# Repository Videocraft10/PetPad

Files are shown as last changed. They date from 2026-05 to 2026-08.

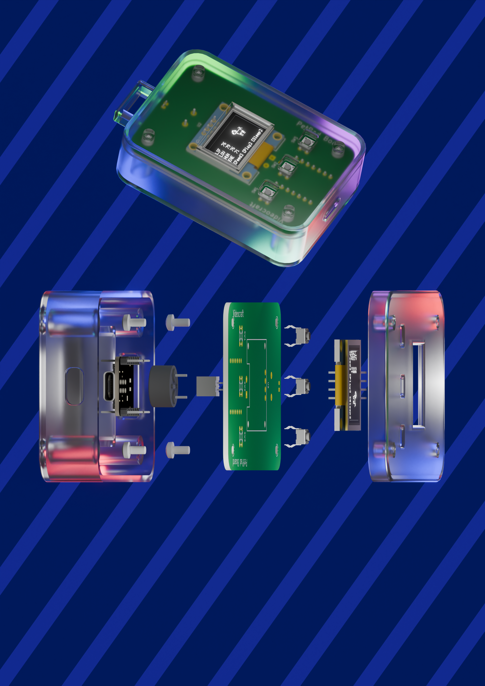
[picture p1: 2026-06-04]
Promo Files/Exports/Zine/Videocraft PetPad Zine Full.png

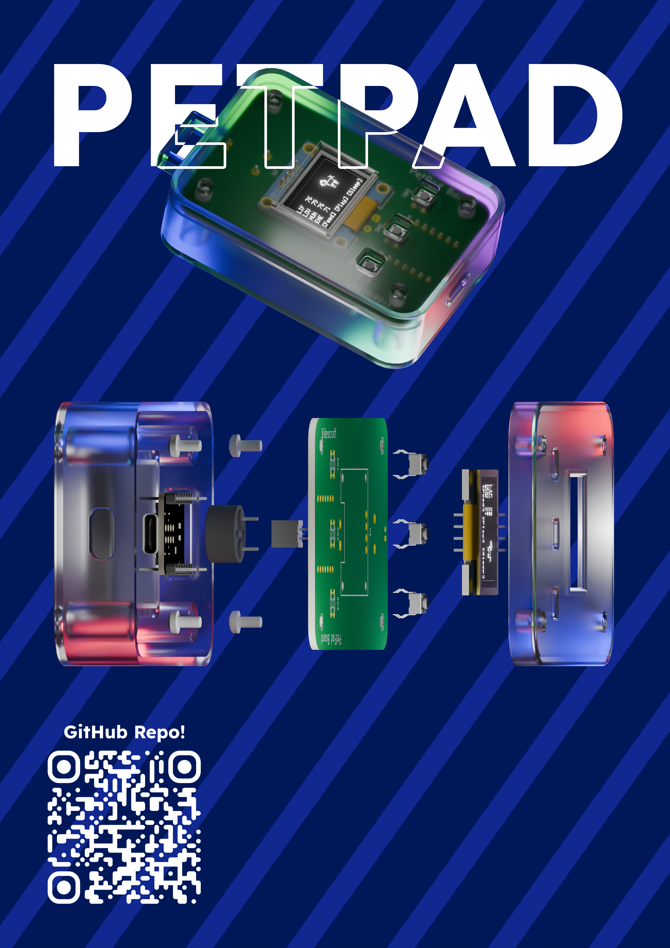
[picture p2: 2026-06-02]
Promo Files/Exports/Zine/Videocraft PetPad Zine 6-2-26.png

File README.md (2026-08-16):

# PetPad [WIP]
PetPad Main

Custom-Made Tamagotchi-Like Device

## Features
Videocraft PetPad Zine v1 BUILD

### Physical
1. USB - C rechargeable 500 mAh battery
2. 3 Tactile buttons for control
3. Buzzer for sound feedback
4. 128x64 OLED Screen

### Digital
1. [WIP] Multiple Pets to obtain
2. Take care (or don't) of your pets to see the visuals change
3. [WIP] Use items obtained randomly on your pets for effects

## Why?
I wanted to create this for a couple of reasons:
1. I wanted a more complex project to work on
2. Tamagotchis are fun and allow me to practice some pixel art skills too
3. And finally, because there was a great guide on the Fallout docs :)

## The PCB
The PCB was made in KiCAD due to the extensive tools and ability to import own footprints that might not be on EasyEDA

### The Schematic


### The Circuit Board
**Front**



**Back**



## The Case

**Overview**



**Top**



**Inside cut**



**Bottom**



## The Firmware
Firmware Video

Visible stats that change over time with visual feedback on overall pets health

## BOM
*Amount used is to make ****ONE**** PetPad*

| Item | LCSC # / Item Links | Single Cost | Amount Used | Fees/Notes | Total Price |
| --- | --- | --- | --- | --- | --- |
| **PCB:** | ---------- | $2 | 1 | $3.12 for shipping | $5.12 |
| ---------- | ---------- | ---------- | ---------- | ---------- | ---------- |
| **Components:** | ---------- | ---------- | ---------- | ---------- | ---------- |
| OLED Screen | [C5248080](https://www.lcsc.com/product-detail/C5248080.html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) | $2.32 | 1 | ---------- | $2.32 |
| Buzzer | [C49246964](https://www.lcsc.com/product-detail/C49246964.html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) | $0.0569 | 1 | Forced to buy 10 | $0.57 |
| Buttons | [C2888493](https://www.lcsc.com/product-detail/C2888493.html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) | $0.0107 | 3 | Forced to buy 50 | $0.54 |
| JST Battery Connector | [C131337](https://www.lcsc.com/product-detail/C131337.html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) | $0.0336 | 1 | Forced to buy 20 | $0.67 |
| 7 Pin Header | [C5360900](https://www.lcsc.com/product-detail/C5360900.html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) | $0.0391 | 2 | Forced to buy 10 | $0.39 |
| 4 Pin Header | [C42431787](https://www.lcsc.com/product-detail/C42431787.html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) | $0.0207 | 1 | Forced to buy 20 | $0.41 |
| Seeed Studio XIAO C6 DIP | [Amazon](https://www.amazon.com/ESP32C6-Supports-Bluetooth-802-15-4-Microsoft/dp/B0D2NKV334?th=1) | $11.99 | 1 | $0.79 tax | $12.78 |
| Battery (140mAh) | [AliExpress](https://www.aliexpress.us/item/3256808031709894.html?channel=twinner) | $1.06 | 1 | NOTE: INSANE SUMMER DEAL USED, NORMAL PRICE $14.23 | $1.06 |
| Screws (M2.5 x 5mm) | [Homedepot](https://www.homedepot.com/p/Prime-Line-M2-5-0-45-x-5-mm-Grade-A2-70-Stainless-Steel-Phillips-Drive-Pan-Head-Metric-Machine-Screws-10-Pack-9130825/311229791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) | $0.433 | 4* | 10 pack | $4.33 |
| Wires | [Amazon]([https://www.adafruit.com/product/3169](https://www.amazon.com/Fielect-Enamelled-Winding-Polyurethane-QA-1-155/dp/B082SGDHTT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)) | $7.48 | less than a foot most likely (WILL HAVE A TON LEFT OVER SO IF YOU HAVE SOMTHING SIMILAR DO NOT BUY) | 30 AWG Magnet Wire Enameled Copper Wire | $7.45 |
| ---------- | ---------- | ---------- | ---------- | ---------- | ---------- |
| *Total:* | ---------- | ---------- | ---------- | ---------- | $37.98 |
| **Fees:** | LCSC Tax $1.25 | ---------- | ---------- | ---------- | [wip] |
| Shipping | LCSC Shipping cost: $10.92 | ---------- | ---------- | ---------- | [wip]|
| Handling | LCSC Handling $3 | ---------- | ---------- | ---------- | $3 |
| ---------- | ---------- | ---------- | ---------- | ---------- | ---------- |
| ***TOTAL*** | ---------- | ---------- | ---------- | ---------- | $50.30 (fee prices not locked in yet) |

## Build BOM
| Item | Discripton | Notes | Fees | -------- | Total |
| --- | --- | --- | --- | --- | --- |
| 3D Printer PLA | Generic 3D printer PLA. Requires a 3D printer to use | Paid $8.34 for 1 kg | ---------- | ---------- | 46g used - $0.38 |
| Sodering Iron | ---------- | Required to soder on components | ---------- | ---------- | $10.55 [here](https://www.amazon.com/Soldering-Digital-Welding-Portable-Electric/dp/B08R3515SF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) |
| ---------- | ---------- | ---------- | ---------- | ---------- | ---------- |
| ***TOTAL*** | ---------- | ---------- | ---------- | ---------- | $10.93 |

***GRAND TOTAL*** = $60.68

## How to Build
> [!NOTE]
> It is recommended to have prior knowledge in electronics and soldering if you want to create one for yourself!

First download the PCB Gerber file from [here](https://github.com/Videocraft10/PetPad/tree/main/PCB%20Files) then send it to your preferred manufacturer! Next buy all of the components from the BOM. For screws and similar items, it is recommended to find the cheapest in your location. Next 3D print the case from here [here](https://github.com/Videocraft10/PetPad/tree/main/Case%20Files) and ensure the PCB fits once it arrives. Next solder on all of the components and screw the PCB into the case! Finally flash the firmware onto it from [here](https://github.com/Videocraft10/PetPad/tree/main/Firmware%20Files/PetPad_Firm) (you might have to build the file on you own computer)

Tada! You now have a PetPad!

(instructions on how to build will improves once I actually physically build one myself :D)

## Software Used
1. KiCAD
2. Autodesk Fusion
3. Blender
4. Visual Studio Code (Arduino Maker Workshop & Wokwi extentsihons)
5. Arduino IDE
6. Adobe Photoshop
7. Adobe Preimimre Pro
8. Visual Studio Code

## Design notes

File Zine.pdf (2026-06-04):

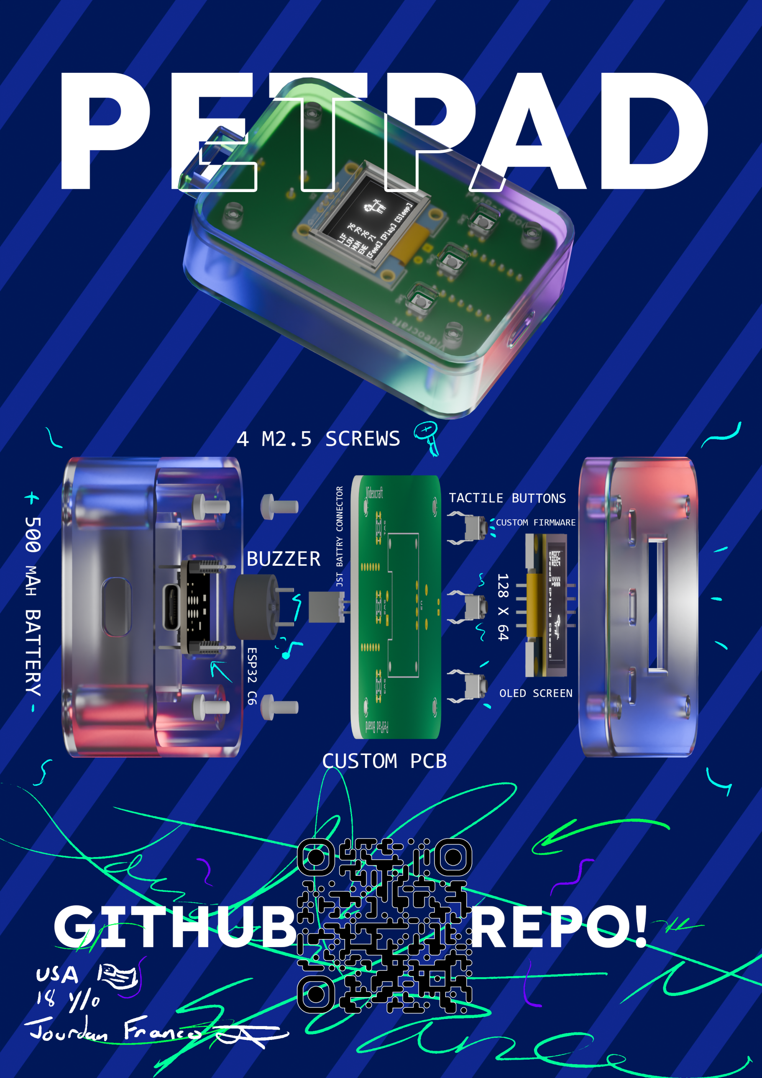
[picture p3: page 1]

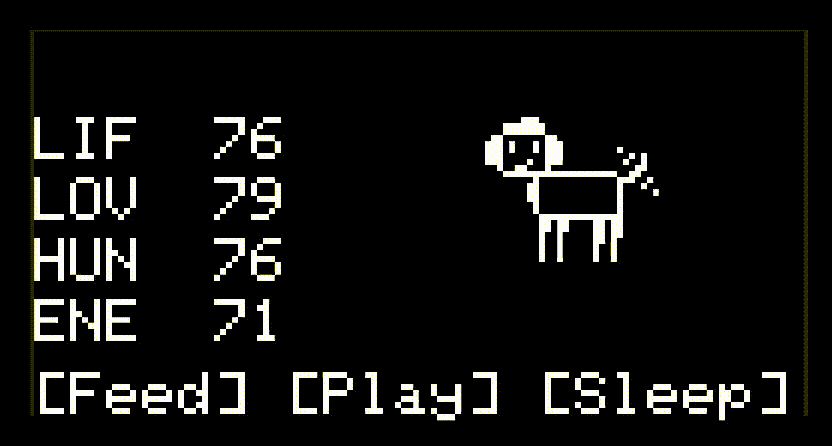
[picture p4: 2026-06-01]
Promo Files/Exports/Firmware Video.gif

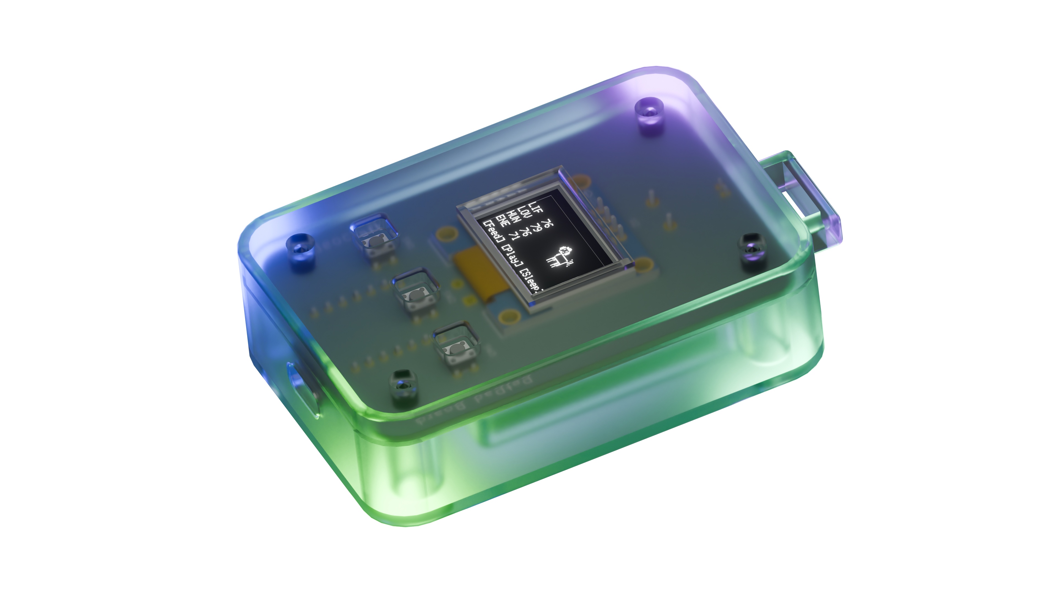
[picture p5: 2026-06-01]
Promo Files/Exports/PetPad Repo Color Cover v0.png

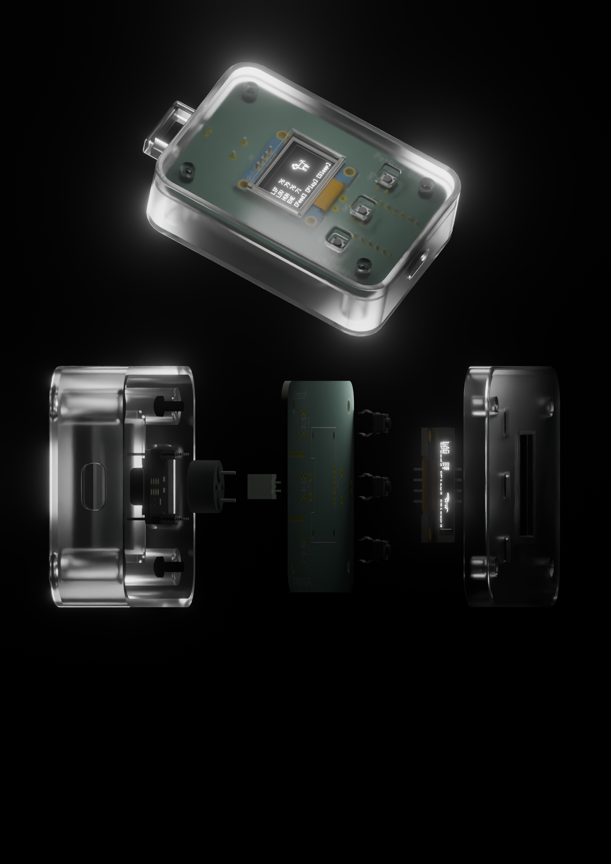
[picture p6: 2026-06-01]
Promo Files/Exports/Zine/Videocraft PetPad Zine 6-1-26.png

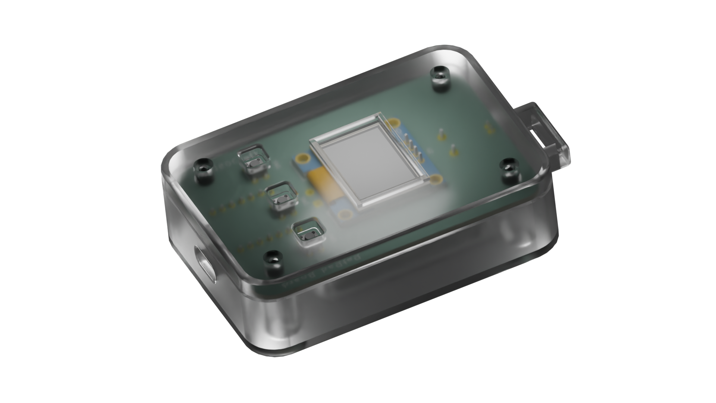
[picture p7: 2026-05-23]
Promo Files/Exports/PetPad Repo Cover v0.png

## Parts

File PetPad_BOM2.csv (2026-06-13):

Item | Link/Description | Single Cost | Amount Used | Notes | Total Price
PCB | - | $2.00 | 1 | $3.12 for shipping | $5.12
OLED Screen | https://www.lcsc.com/product-detail/C5248080.html | $2.32 | 1 | - | $2.32
Buzzer | https://www.lcsc.com/product-detail/C49246964.html | $0.0569 | 1 | Forced to buy 10 | $0.57
Buttons | https://www.lcsc.com/product-detail/C2888493.html | $0.0107 | 3 | Forced to buy 50 | $0.54
JST Battery Connector | https://www.lcsc.com/product-detail/C131337.html | $0.0336 | 1 | Forced to buy 20 | $0.67
7 Pin Header | https://www.lcsc.com/product-detail/C5360900.html | $0.0391 | 2 | Forced to buy 10 | $0.39
4 Pin Header | https://www.lcsc.com/product-detail/C42431787.html | $0.0207 | 1 | Forced to buy 20 | $0.41
Seeed Studio XIAO C6 DIP | https://www.amazon.com/ESP32C6-Supports-Bluetooth-802-15-4-Microsoft/dp/B0D2NKV334 | $11.99 | 1 | $0.79 tax | $12.78
Battery (500mAh) | https://www.aliexpress.us/item/3256808031709894.html | $1.06 | 1 | NOTE: INSANE SUMMER DEAL USED, NORMAL PRICE $14.23 | $1.06
Screws (M2 x 5mm) | https://www.homedepot.com/p/Prime-Line-M2-5-0-45-x-5-mm-Grade-A2-70-Stainless-Steel-Phillips-Drive-Pan-Head-Metric-Machine-Screws-10-Pack-9130825/311229791 | $0.433 | 4 | 10 pack | $4.33
Wires | https://www.amazon.com/Fielect-Enamelled-Winding-Polyurethane-QA-1-155/dp/B082SGDHTT | $7.48 | less than a foot | 30 AWG Magnet Wire. WILL HAVE A TON LEFT OVER SO IF YOU HAVE SOMTHING SIMILAR DO NOT BUY | $7.45
Subtotal | - | - | - | - | $37.98
LCSC Tax | - | - | - | - | $1.25
LCSC Shipping | - | - | - | - | $10.92
LCSC Handling | - | - | - | - | $3.00
TOTAL (PetPad Estimated) | - | - | - | fee prices not locked in yet | $50.30
3D Printer PLA | Generic 3D printer PLA. Requires a 3D printer to use. | $8.34 for 1 kg | 46g used | - | $0.38
Soldering Iron | https://www.amazon.com/Soldering-Digital-Welding-Portable-Electric/dp/B08R3515SF | $10.55 | 1 | Required to solder on components | $10.55
TOTAL (Build Tools) | - | - | - | - | $10.93

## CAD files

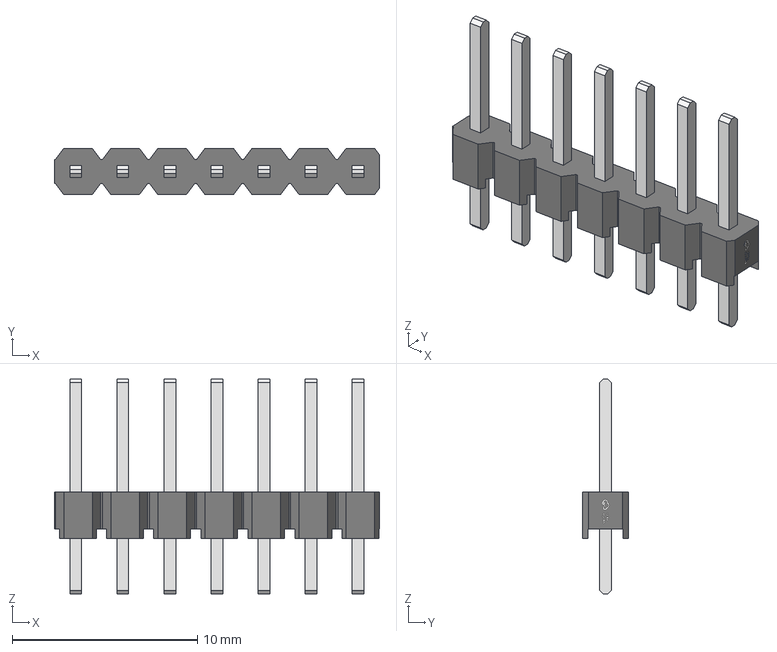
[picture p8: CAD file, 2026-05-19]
CAD Files/Componet STEP Files/7 Pin header.step
17.5 x 2.50 x 11.6 mm

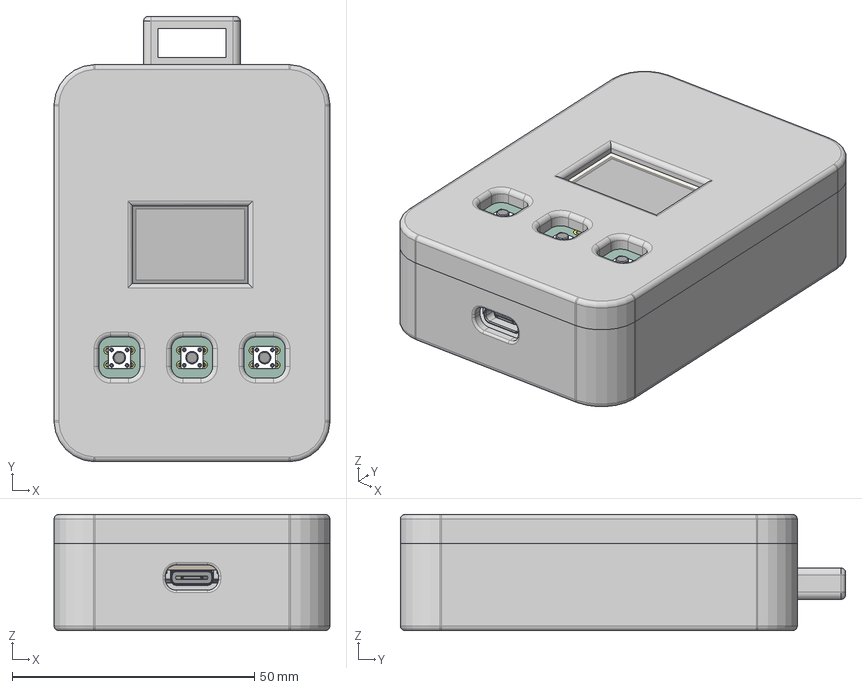
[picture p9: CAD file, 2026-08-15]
CAD Files/Videocraft PetPad.step
57.0 x 92.0 x 24.0 mm
DIN 7985 - M2.5x5-H H Steel 4.6 Zinc x 4

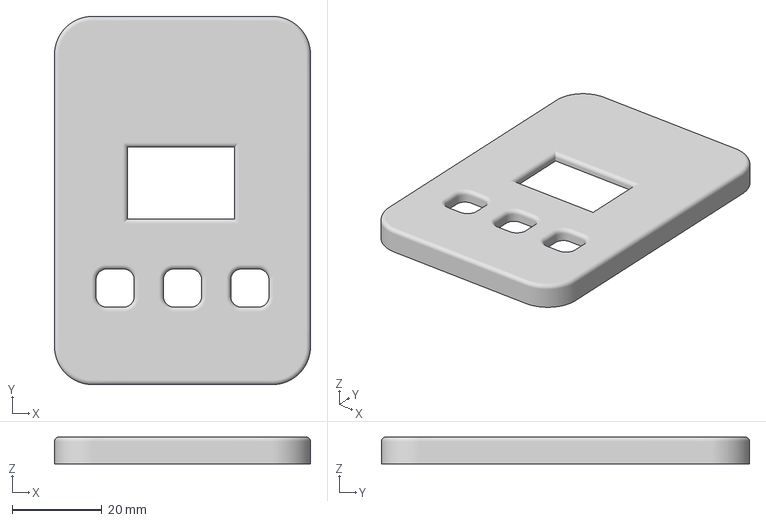
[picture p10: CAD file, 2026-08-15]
Case Files/PetPad Case Top.3mf
57.0 x 82.0 x 6.00 mm

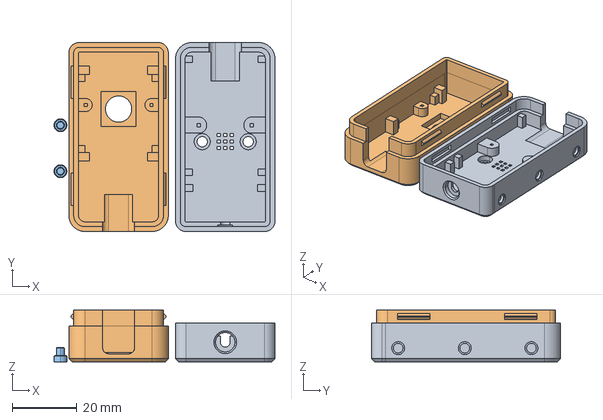
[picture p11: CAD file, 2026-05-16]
KiCad Files/OPL_Kicad_Library-master/Grove Vision AI V2 Library/himax.stp
68.4 x 58.5 x 16.1 mm

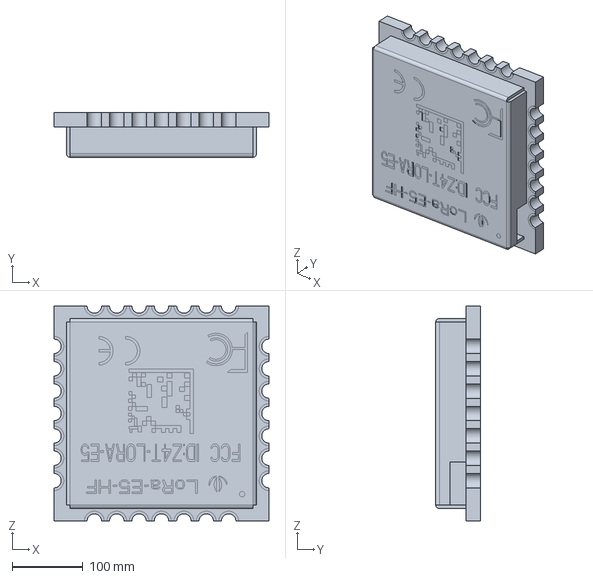
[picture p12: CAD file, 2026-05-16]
KiCad Files/OPL_Kicad_Library-master/Seeed Studio Wio Series/Wio-E5-LE/LoRa-E5-LE-HF_3D_File.stp
304.8 x 63.8 x 304.8 mm

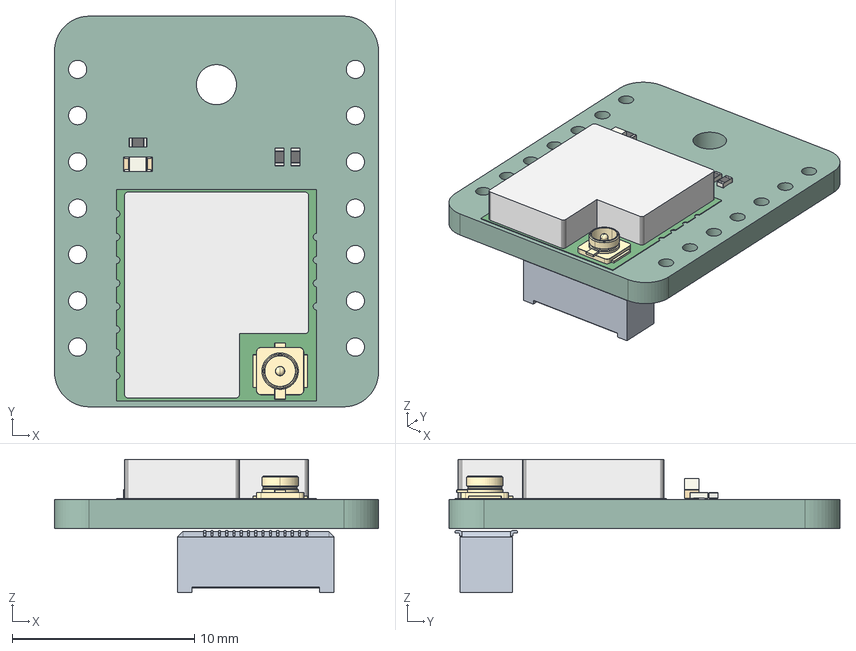
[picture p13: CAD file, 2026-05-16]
KiCad Files/OPL_Kicad_Library-master/Seeed Studio Wio Series/Wio-SX1262/Wio-SX1262_for_XIAO_3D_file.step
17.8 x 21.4 x 7.30 mm
R_0402_1005Metric x 3
LED_0603_1608Metric
PCB
BF04-30pin-35H
Wio-SX1262 for XIAO V1.0_PCB

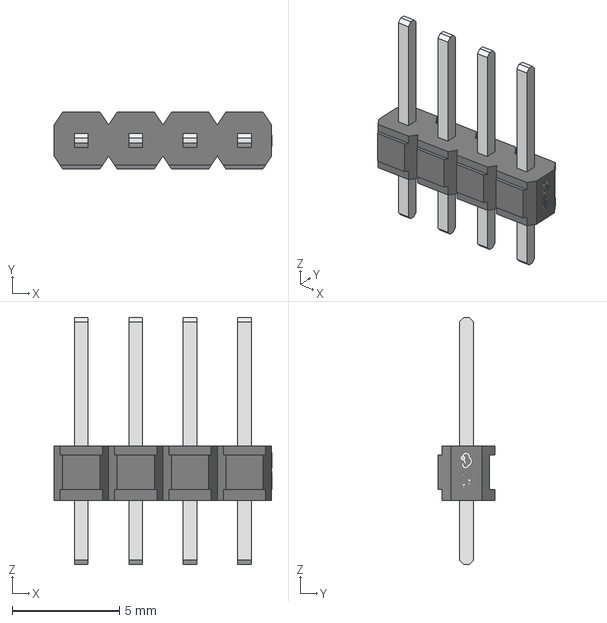
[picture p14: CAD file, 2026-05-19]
CAD Files/Componet STEP Files/4 Pin Header.step
10.2 x 2.66 x 11.5 mm

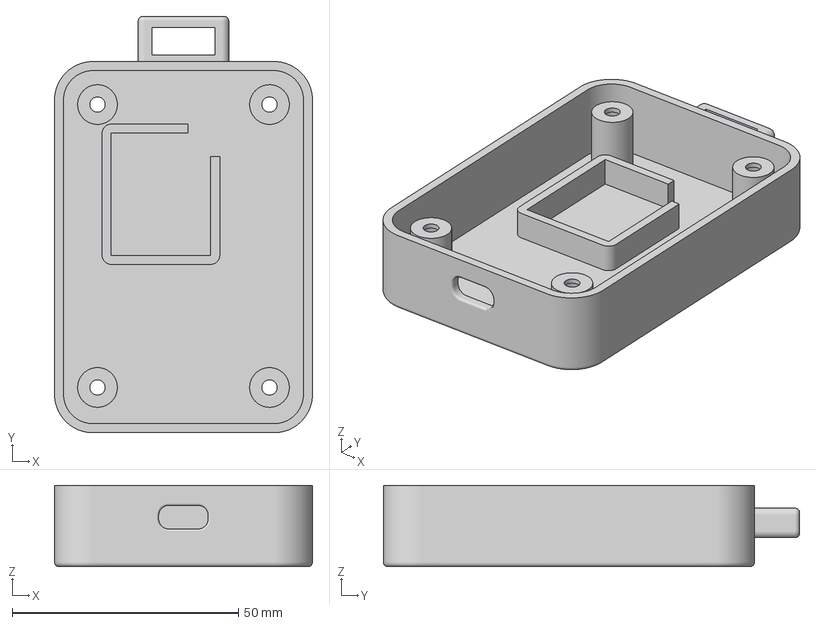
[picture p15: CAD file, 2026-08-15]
Case Files/PetPad Case Bottom.3mf
57.0 x 92.0 x 18.0 mm

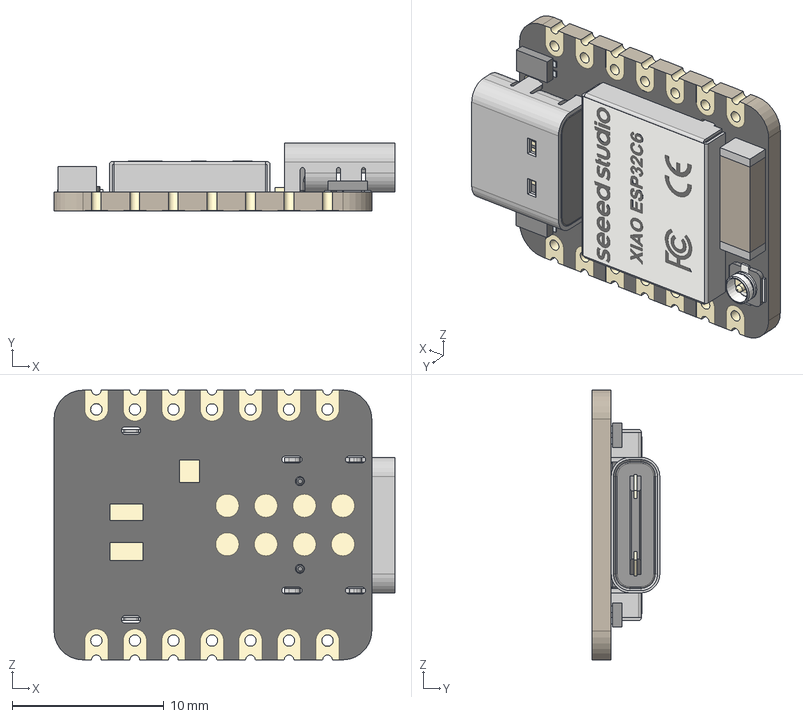
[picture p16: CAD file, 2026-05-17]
CAD Files/Componet STEP Files/seeed-studio-xiao-esp32c6-v2.step
22.5 x 4.46 x 17.8 mm
BOSS-EXTRUDE14_8_
BOSS-EXTRUDE7_4_
BOSS-EXTRUDE7_3_
BOSS-EXTRUDE14_4_
BOSS-EXTRUDE14_2_
BOSS-EXTRUDE14_11_
BOSS-EXTRUDE7_7_
BOSS-EXTRUDE14_9_
BOSS-EXTRUDE14_3_
BOSS-EXTRUDE14_7_
MIRROR2
BOSS-EXTRUDE14_5_
BOSS-EXTRUDE14_12_
BOSS-EXTRUDE7_8_
BOSS-EXTRUDE7_1_
BOSS-EXTRUDE14_10_
BOSS-EXTRUDE7_9_
BOSS-EXTRUDE14_6_
BOSS-EXTRUDE14_1_
BOSS-EXTRUDE7_6_
BOSS-EXTRUDE7_2_
CUT-EXTRUDE5
BOSS-EXTRUDE7_5_
Shield
Pins x 2
U.FL-R-SMT-1_10_ v1

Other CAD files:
CAD Files/Videocraft PetPad.f3z
CAD Files/Videocraft PetPad.obj
Promo Files/PetPad Main.blend
Promo Files/PetPad Zine.blend

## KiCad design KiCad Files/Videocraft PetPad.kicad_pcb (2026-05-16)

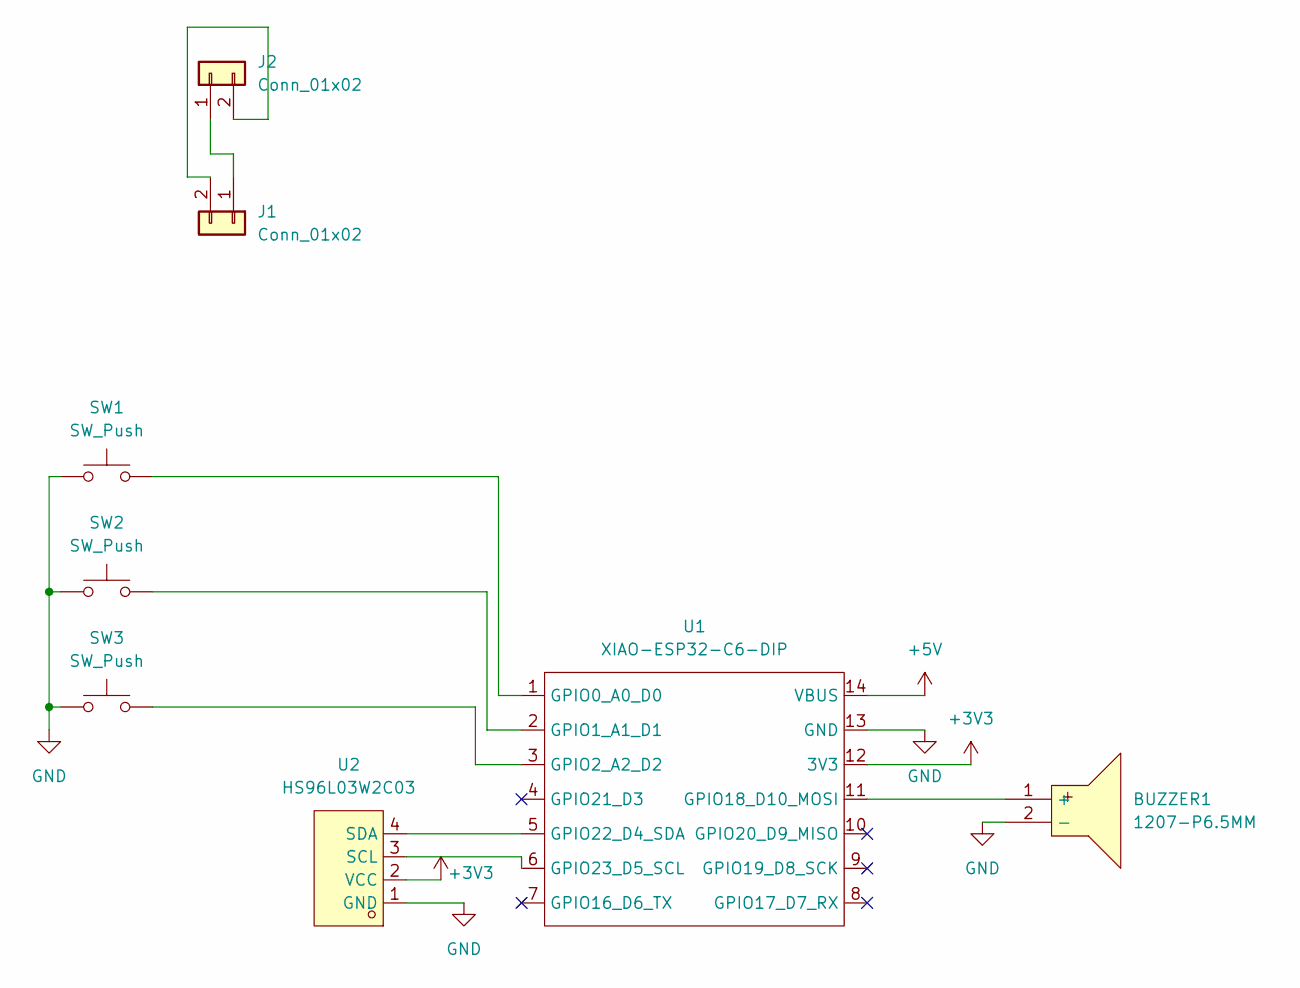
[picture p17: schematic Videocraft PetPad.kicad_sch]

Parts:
BUZZER1: 1207-P6.5MM; BUZ-TH_BD12.5-P6.50-D1.4; MPN 1207-P6.5MM; LCSC Part C49246964
J1: Conn_01x02; SolderWire-0.5sqmm_1x02_P4.6mm_D0.9mm_OD2.1mm
J2: Conn_01x02; JST_PH_B2B-PH-K_1x02_P2.00mm_Vertical
SW1, SW2, SW3: SW_Push; SW-TH_4P-L4.5-W4.5-P3.00-LS4.8
U1: XIAO-ESP32-C6-DIP
U2: HS96L03W2C03; OLED-TH_L27.8-W27.2-P2.54_C9900033791; MPN HS96L03W2C03; LCSC Part C5248080

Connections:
+3V3: U1.12 (3V3), U2.2 (VCC)
+5V: U1.14 (VBUS)
GND: BUZZER1.2 (-), SW1.1, SW2.1, SW3.1, U1.13 (GND), U2.1 (GND)
unnamed: BUZZER1.1 (+), U1.11 (GPIO18_D10_MOSI)
unnamed: J1.1, J2.1
unnamed: J1.2, J2.2
unnamed: SW1.2, U1.1 (GPIO0_A0_D0)
unnamed: SW2.2, U1.2 (GPIO1_A1_D1)
unnamed: SW3.2, U1.3 (GPIO2_A2_D2)
unnamed: U1.5 (GPIO22_D4_SDA), U2.4 (SDA)
unnamed: U1.6 (GPIO23_D5_SCL), U2.3 (SCL)

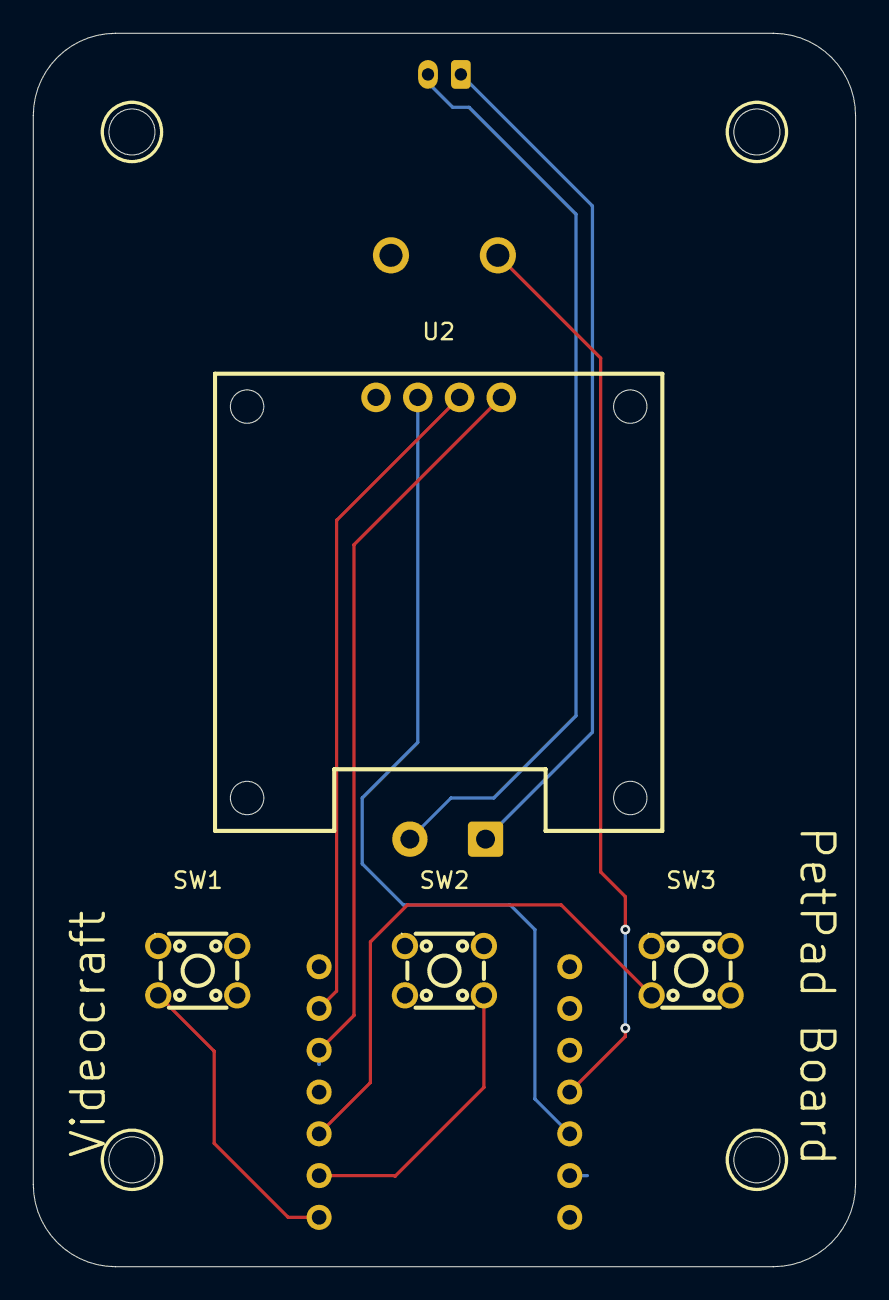
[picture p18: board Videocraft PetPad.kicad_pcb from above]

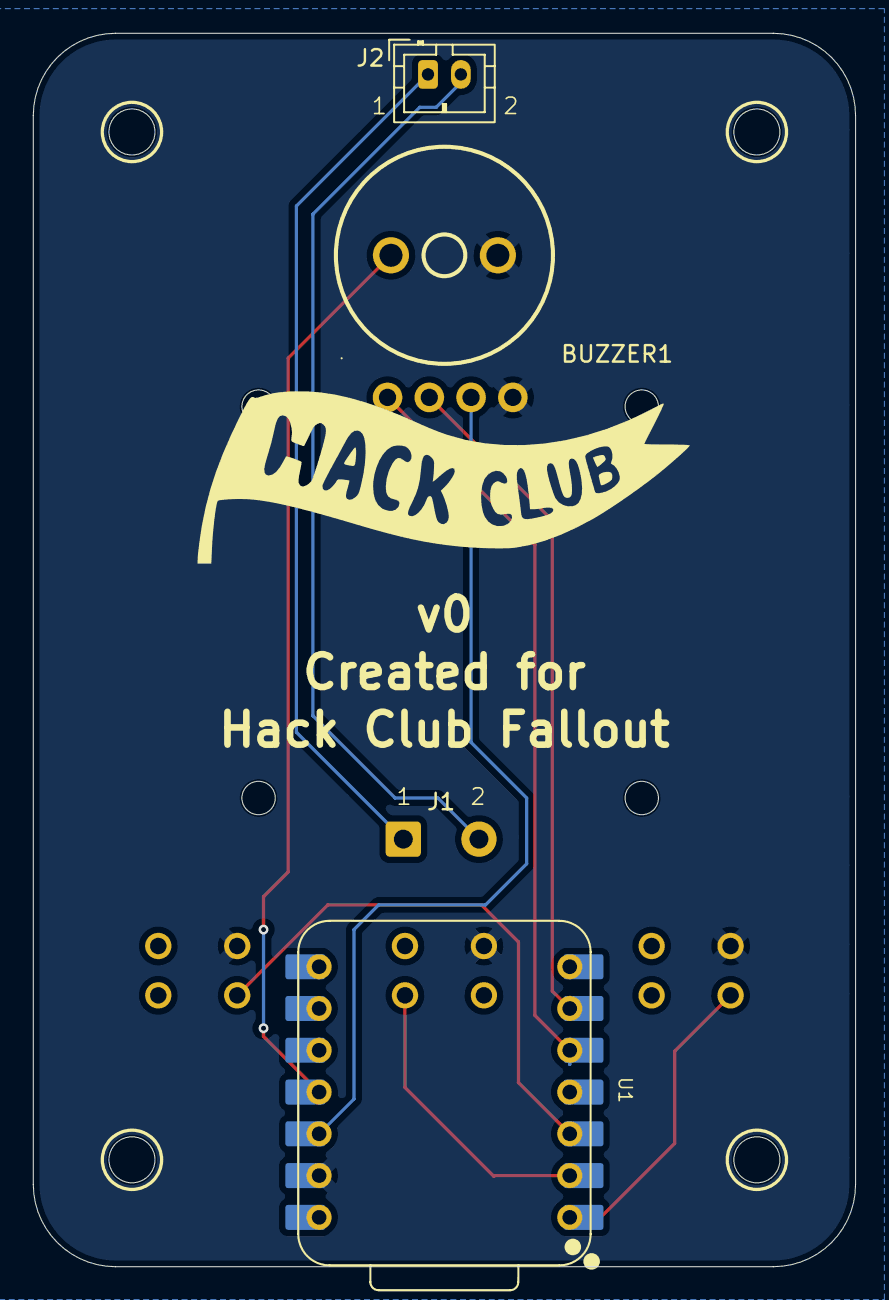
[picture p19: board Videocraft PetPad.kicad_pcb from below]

Board: 2 copper layers, 50.0 x 75.0 mm, 8 parts (4 on the bottom side), 10 nets.

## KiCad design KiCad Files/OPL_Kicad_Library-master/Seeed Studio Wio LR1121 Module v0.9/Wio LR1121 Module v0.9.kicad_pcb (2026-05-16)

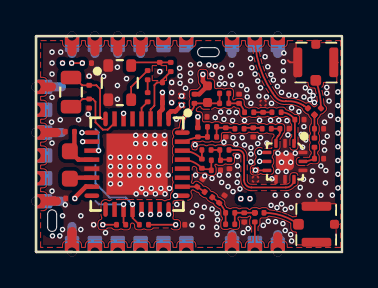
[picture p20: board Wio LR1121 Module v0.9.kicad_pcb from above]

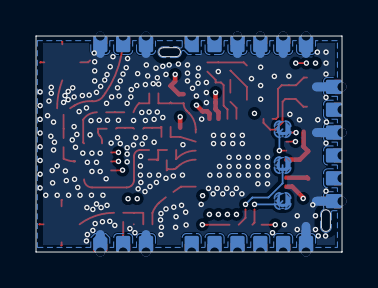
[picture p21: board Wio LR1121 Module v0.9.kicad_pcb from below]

Board: 4 copper layers, 17.0 x 12.0 mm, 69 parts (3 on the bottom side), 47 nets.

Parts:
C1, C2, C3, C4, C5, C6, C7, C8, C9, C11, C12, C13, C14, C15, C18, C19, C20, C22, C24, C25, C26, C27, C28, C29, C30, C31, C32, C33, C34, C35, C36, C37, C38, C39, C40, C41, C42, C43: C0201
FB1: L0201
J1, J2: U-FL4P-SMD-1_7X1_7X1_0MM
L1: L0402
L2, L3, L5, L6, L7, L8, L9, L10, L11, L13: L0201
L12: L0603
OSC1: X4_SMD_2_5X2_0MM
R1, R2, R3, R4, R5, R7, R8, R9: R0201
TP23, TP24, TP25: TP35S_SMD
U1: QFN12_0D5_2X2X0_55MM
U2: QFN32_0D5_5X5MM_EP3P3MM
U3: MODULE24_1D27_17X12MM
X1: X2_SMD_2X1_2MM

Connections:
2.4G_RF: C43.2, U3.2
GND_POWER: C3.2, C4.2, C5.2, C6.2, C7.2, C8.2, C11.2, C12.2, C13.2, C14.2, C15.2, C18.2, C19.2, C22.2, C25.2, C26.2, C28.2, C29.2, C30.2, C31.2, C32.2, C33.2, C35.2, C36.2, C37.2, C38.2, C40.2, C42.2, J1.2, J1.3, J1.4, J2.2, J2.3, J2.4, OSC1.1, OSC1.2, U1.2, U1.7, U1.8, U1.10, U1.12, U1.13, U2.13, U2.33, U3.1, U3.3, U3.9, U3.10, U3.13, U3.15, U3.16, U3.17, U3.18, U3.19, U3.22, U3.24
HP_LF: C1.1, L1.2, L2.1, R1.2, U2.32
LP_LF: C9.1, L6.1, L13.2, U2.31
LR1121_BUSY: U2.25, U3.8
LR1121_DIO8: U2.10, U3.11
LR1121_DIO9_INT: U2.9, U3.12
LR1121_RSTN: C42.1, R7.2, U2.6, U3.14
LR1121_SPI_MISO: U2.21, U3.7
LR1121_SPI_MOSI: U2.22, U3.6
LR1121_SPI_NSS: U2.24, U3.4
LR1121_SPI_SCK: U2.23, U3.5
MCU_DIO5: R3.1, TP23.1, U2.20
MCU_DIO6: R2.1, TP24.1, U2.19
MCU_DIO7: R5.1, TP25.1, U2.11
N18704063: C25.1, U2.7, X1.1
N18704080: C26.1, U2.8, X1.2
N18704168: L12.2, U2.14
N18704177: C31.1, L12.1, U2.12
N18704981: C9.2, C37.1, L6.2, L7.1
N18704990: C1.2, C3.1, L2.2, L3.1
N18705097: C2.1, C4.1, L3.2
N18705182: C38.1, C39.1, L7.2
N18705449: C18.1, C39.2, U1.3
N18705460: C2.2, C5.1, U1.1
N18706098: C20.2, C40.1, C41.1, L9.2
N18706198: C41.2, U1.9
N18706539: C24.1, C29.1, L10.2, L11.1
N18706650: C24.2, C27.1, C30.1, C43.1, L11.2
N18706671: C27.2, J2.1
N18712116: C14.1, L5.1, U1.11
N18712319: C36.1, FB1.2, OSC1.4
N18712325: C34.1, OSC1.3
N18712327: C34.2, R4.1
N18713044: C15.1, L5.2, R8.1, R9.1
N18751757: J1.1, R8.2
RFIO_HF: C28.1, L10.1, U2.26
RFI_N: C22.1, L8.2, L9.1, U2.29
RFI_P: C20.1, L8.1, U2.30
RFSW0_V1: C33.1, R3.2, U1.4
RFSW1_V2: C32.1, R2.2, U1.5
RFSW_VDD: C19.1, R5.2, U1.6
SUBG_RF: R9.2, U3.23
VDD_RF: C11.1, C12.1, C13.1, R7.1, U2.2, U2.15, U3.20, U3.21
VR_PA: C6.1, C7.1, C8.1, L1.1, L13.1, R1.1, U2.1
VTCXO: C35.1, FB1.1, U2.3
XTA: R4.2, U2.4

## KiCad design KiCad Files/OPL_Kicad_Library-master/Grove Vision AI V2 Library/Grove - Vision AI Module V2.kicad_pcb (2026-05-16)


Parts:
BOOT1: SW_Push; SW_Push_1P1T_NO_Vertical_Wuerth_434133025816
C1, C2, C17, C18, C19: 1uF; C0402
C3: 10nF; C0402
C4, C6, C7, C9, C10, C28, C34: 4.7uF; C0402
C5, C8, C13, C20, C21, C22, C23, C24, C25, C26, C27, C29, C30, C31, C32, C35, C36, C39: 100nF; C0402
C11, C37: 10uF; C0402
C14, C15: 12pF; C0402
C16: 220nF; C0402
D1, D2, D3, D4: B5819WS; D0805_SOD323
D5, D6, D7, D8: DNP; R0402; MPN DF2S6.8FS
J1: USB_C_Receptacle_USB2.0; USB2.0-TYPE-C
J2: Conn_01x15_MountingPin; FPC_DNC_15P_1.0mm
J3: Conn_01x04_MountingPin; 4P-SMD-2.0mm-RIGHT
J5: ST-TF-MR267; SD-TF-MR267; MPN SD-TF-MR267
L1: VLS201610HBX-4R7M-1; L0806
L2, L3: 470nH; L0603
LED1: Yellow; LED0402
LED2: Green; LED0402
M1: XIAO Connector/DNP; XIAO_Socket
MIC1: MSM261D3526H1CPM; MIC6P-3.5X2.65X0.94MM
Q1, Q2, Q3, Q4, Q5: CJ1012; SOT523
R1, R4, R13, R14, R15, R19, R20, R21, R22, R40: 2.2k; R0402
R2, R3, R36: 5.1k; R0402
R5, R7, R23, R24: 10k; R0402
R6, R16, R32, R33: 100K; R0402; Power Rating 1%; MPN RC0402JR-074K7L
R8, R31, R38: 10K; R0402; Power Rating 5%; MPN RC0402JR-074K7L
R9, R12, R17, R18, R25, R27, R28: DNP; R0402
R10, R11, R37: 100k; R0402
R26, R34: 22K; R0402; Power Rating 1%; MPN RC0402JR-074K7L
R29, R30, R39: 0R; R0402
R35: 510k; R0402
RST1: SW_Push; SW_Push_1P1T_NO_Vertical_Wuerth_434133025816
TP1, TP2, TP3: Test Point; TP-D35MIL; Part Type Test Point
U1: HX6538; WLCSP65_5.6x2.3x0.56mm
U2: CH343P; QFN-16-EP_3x3mm_P0.5mm_EP1x1mm
U3: WR0331-18FF4R; X2SON-4
U4, U6: SY80004DQD; DFN6-0.5-1.5X1.5X0.65MM; MPN SY80004DQD
U5: W25Q128JWSIQ; SOIC-8_5.23x5.23mm_P1.27mm
X1: 24MHz; 4P2016

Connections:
1V8: C13.1, C19.2, C20.1, C21.1, C28.1, C29.2, Q1.1 (G), Q2.1 (G), R5.1, R21.2, R22.2, R25.1, TP2.1 (T), U1.F3 (VDDIO_SIF1), U1.G3 (VDDA_RX), U1.H5 (VDDA_TX), U1.L2 (VDDIO_SIF2), U3.1 (OUT), U5.8 (VCC)
/0V9: C4.1, C7.1, L1.2, U1.L4 (DCDC_OUT)
BOOTOPT0: D3.1 (K), R11.1, U1.F4 (BOOT_OPT)
GND: C1.2, C2.2, C3.2, C4.2, C5.2, C6.2, C7.2, C8.1, C9.2, C10.2, C11.1, C13.2, C14.2, C15.1, C17.2, C18.2, C19.1, C20.2, C21.2, C22.2, C23.2, C24.1, C25.1, C26.2, C27.1, C28.2, C29.1, C30.1, C31.2, C34.2, C35.1, C37.1, C39.1, D5.1, D6.1, D7.1, D8.1, J1.A1_B1_A12_B12 (GND), J1.S1 (SHIELD), J2.1, J2.4, J2.7, J2.10, J2.MP (MountPin), J3.4, J3.MP (MountPin), J5.S1 (SHD1), J5.S2 (SHD2), J5.S3 (SHD3), J5.S4 (SHD4), J5.T6 (VSS), LED2.1 (K), M1.13 (GND), MIC1.4 (GND), MIC1.5 (L/R), MIC1.6 (GND), Q3.2 (S), R2.2, R3.2, R10.2, R11.2, R23.2, R26.1, R34.1, R37.2, RST1.2, TP3.1 (T), U1.C5 (GND1), U1.G4 (GND2), U1.H3 (GND3), U1.L3 (GND4), U1.M2 (GND5), U1.M4 (GND6), U2.2 (GND), U2.17 (EPAD), U3.2 (GND), U3.T (GND), U4.4 (GND), U5.4 (GND), U6.4 (GND), X1.2 (1), X1.4 (3)
GROVE_5V_IN: C18.1, C34.1, C35.2, J3.3, R14.1, R15.1, R31.2, R32.2, U6.6 (IN)
I2CS0_SCL/5V: J3.1, Q4.3 (D), R14.2
I2CS0_SDA/5V: J3.2, Q5.3 (D), R15.2
M_3V3_SCL: J2.13, Q1.3 (D), R19.2
M_3V3_SDA: J2.14, Q2.3 (D), R20.2
unnamed: BOOT1.2, R4.2
unnamed: D1.2 (A), R36.2
unnamed: C9.1, C10.1, C27.2, D2.1 (K), D4.1 (K), R6.2, R8.2, U4.6 (IN)
unnamed: BOOT1.1, D3.2 (A), R36.1
unnamed: J1.A5 (CC1), R2.1
unnamed: J1.B5 (CC2), R3.1
unnamed: LED1.2 (A), R38.1
unnamed: LED1.1 (K), Q3.3 (D)
unnamed: LED2.2 (A), R24.2
unnamed: M1.12 (3V3), R39.2
unnamed: MIC1.2 (CLK), R29.1
unnamed: MIC1.3 (DATA), R30.1
unnamed: Q3.1 (G), R37.1, R40.2
unnamed: R10.1, U1.E4 (TEST_MODE)
unnamed: L1.1, U1.L5 (VX1)
unnamed: C14.1, R35.1, U1.G2 (XTAL_24M_I), X1.3 (4)
unnamed: C15.2, R35.2, U1.F1 (XTAL_24M_O), X1.1 (2)
unnamed: C16.2, U2.13 (RTS)
unnamed: R8.1, U4.1 (EN)
unnamed: C32.1, R16.1, R26.2, U4.3 (FB)
unnamed: L2.1, U4.5 (LX)
unnamed: R6.1, U4.2 (PG)
unnamed: R31.1, U6.1 (EN)
unnamed: C36.1, R33.1, R34.2, U6.3 (FB)
unnamed: L3.1, U6.5 (LX)
unnamed: R32.1, U6.2 (PG)
PA0/3V3: M1.1 (D0/A0), U1.D4 (PA0)
PA1/VMUTE/3V3: J2.11, U1.C4 (PA1)
PA2/I2CS0_SCL/3V3: M1.6 (D5/SCL), Q4.2 (S), R1.1, R17.2, U1.A4 (PA2)
PA3/I2CS0_SDA/3V3: M1.5 (D4/SDA), Q5.2 (S), R13.1, R18.2, U1.B4 (PA3)
PB0/RX0/3V3: U1.A5 (PB0), U2.4 (TXD)
PB1/TX0/3V3: U1.B5 (PB1), U2.5 (RXD)
PB2/SSPIM_DO/3V3: D7.2, J5.T3 (CMD), M1.11 (D10/MOSI), R12.2, U1.N5 (PB2)
PB3/SSPIM_DI/3V3: D5.2, J5.T7 (DAT0), M1.10 (D9/MISO), R9.2, U1.M3 (PB3)
PB4/SSPIM_SCLK/3V3: D6.2, J5.T5 (CLOCK), M1.9 (D8/SCK), R27.2, U1.N4 (PB4)
PB5/SSPIM_~CS/3V3: D8.2, J5.T2 (CD/DAT3), R28.2, U1.N3 (PB5)
PB6/UART1_RX/3V3: M1.7 (D6/TX), U1.N1 (PB6)
PB7/UART1_TX/3V3: M1.8 (D7/RX/SS), U1.M1 (PB7)
PB8/3V3: M1.3 (D2/A2), U1.L1 (PB8)
PB9/PDM_CLK/3V3: R29.2, U1.F5 (PB9)
PB10/PDM_DATA0/3V3: R30.2, U1.G5 (PB10)
PB11/3V3: M1.2 (D1/A1), U1.J3 (PB11)
QSPI_CLK: U1.C2 (QSPI_CLK), U5.6 (CLK)
QSPI_CS: R5.2, U1.B2 (QSPI_CS), U5.1 (~CS)
QSPI_D0: U1.B1 (QSPI_DIO0), U5.5 (DI(IO0))
QSPI_D1: U1.D3 (QSPI_DIO1), U5.2 (DO(IO1))
QSPI_D2: U1.A1 (QSPI_DIO2), U5.3 (IO2)
QSPI_D3: U1.E3 (QSPI_DIO3), U5.7 (IO3)
RST: C3.1, C16.1, M1.4 (D3/A3), R7.1, RST1.1, U1.E5 (RESETN)
RX_CK_N: J2.8, U1.E2 (RX_CKN)
RX_CK_P: J2.9, U1.F2 (RX_CKP)
RX_D0_N: J2.2, U1.D2 (RX_DN0)
RX_D0_P: J2.3, U1.C1 (RX_DP0)
RX_D1_N: J2.5, U1.D1 (RX_DN1)
RX_D1_P: J2.6, U1.E1 (RX_DP1)
SEN_D1/SD~INSERT: J5.G1 (SWITCH), R25.2, U1.G1 (SEN_D1)
SEN_I2CM_SCL: Q1.2 (S), R21.1, U1.A3 (SEN_I2CM_SCL)
SEN_I2CM_SDA: Q2.2 (S), R22.1, U1.B3 (SEN_I2CM_SDA)
UD+: J1.A6 (D+), J1.B6 (D+), U2.7 (D+)
UD-: J1.A7 (D-), J1.B7 (D-), U2.8 (D-)
USER_LED/1V8: R40.1, U1.K2 (SEN_D2)
USR_BTN/1V8: D1.1 (K), R23.1, U1.H1 (SEN_D0)
V33IO: C2.1, C31.1, U2.1 (VIO), U2.6 (V3)
VBUS: C1.1, C30.2, D4.2 (A), J1.A4_B4_A9_B9 (VBUS), U2.3 (VDD5), U2.9 (VBUS)
VCC_3V3: C5.1, C6.1, C8.2, C11.2, C17.1, C22.1, C23.1, C24.2, C25.2, C26.1, C32.2, C36.2, C37.2, C39.2, J2.15, J5.T4 (VDD), L2.2, L3.2, MIC1.1 (VDD), Q4.1 (G), Q5.1 (G), R1.2, R4.1, R7.2, R9.1, R12.1, R13.2, R16.2, R17.1, R18.1, R19.1, R20.1, R24.1, R27.1, R28.1, R33.2, R38.2, R39.1, TP1.1 (T), U1.D5 (VDDIO_AON), U1.M5 (VDDA_DCDC), U1.N2 (VDDIO_PIF), U3.3 (EN), U3.4 (IN)
VMAIN: D2.2 (A), M1.14 (VUSB)

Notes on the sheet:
MIPI CSI
AON 3V3
MIPI DSI
PIF 3V3
SIF only 1V8
Imax=600mA
23/11/14
Grove - Vision AI Module V2
JN.FUONG



Board: 4 copper layers, 40.0 x 20.0 mm, 112 parts (31 on the bottom side), 75 nets.

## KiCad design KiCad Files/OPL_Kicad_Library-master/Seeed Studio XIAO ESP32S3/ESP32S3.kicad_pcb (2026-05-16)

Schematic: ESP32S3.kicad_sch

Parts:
ANT1: U.FL-R-SMT-1; U-FL3P-SMD-2.6X2.6X1.0MM
BAT0: VBAT; TP-80X40MIL
C1, C2, C17, C20: DNP; C0201
C3, C9, C13, C16: 2.2uF; C0201
C4, C5, C6: 4.7uF; C0201
C7, C8, C28: 10pF; C0201
C10, C21, C25, C26: 1uF; C0201
C11, C14, C15, C19, C22, C23, C29, C30: 100nF; C0201
C12: 10nF; C0201
C18: 1pF; C0201
CHG0: RED; LED-0402
D2: LMBR4010BST5G; DFN1006-2L
D3: Yellow; LED-0402
GND0: GND; TP-80X40MIL
J1, J2: DNP; H7-HALF-HOLE-2.54
J3: DF40C-30DP-0.4V(51); BTB30-0.4-7.52X2.97X1.14
K1, K2: SKTAAAE010/311021459; SW4-SMD-2.8-2.6X1.6X0.53MM
L1: 2nH; L0201
L2: 3.3nH; L0201
L3: DNP; L0201
L4: 470nH; L0603
Q1: LP0404N3T5G; PMOS_1.0_0.6_0.35MM
R1, R2: 5.1K; R0201
R3, R4: 22R; R0201
R5: 0R; R0201
R6: 499R; R0201
R7, R8, R11: 10K; R0201
R9: 100K; C0201
R10: 220K; R0201
R13: 249K; R0201
R15: 1.5K; R0201
TP1, TP2, TP3, TP4, TP5, TP6, TP7, TP8: TEST-POINT'4545'; TP-D45MIL
U1: ESP32-S3R8; QFN56G-0.4-7X7MM
U3: SGM6029CYG/TR; BGA6-0.35-0.745X10.95X0.4MM
U4: SGM40567-4.2XG/TR; WLCSP-0.4-0.92X1.16X0.4MM
U5: GD25Q64ENIGR; USON8-0.8-4X3MM
USB0: UBF31-0171; USB2.0-TYPE-C
X1: 40MHz/306011364; X4-SMD-1.6X1.2X0.35MM

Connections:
D0/A0: J2.1, J2.13 (1), U1.6 (GPIO1)
D1/A1: J2.2, J2.14 (2), U1.7 (GPIO2)
D2/A2: J2.3, J2.15 (3), J3.2, U1.8 (GPIO3)
D3/A3: J2.4, J2.16 (4), U1.9 (GPIO4)
D4/I2C_SDA: J2.5, J2.17 (5), U1.10 (GPIO5)
D5/I2C_SCL: J2.6, J2.18 (6), U1.11 (GPIO6)
D6/TX: J2.7, J2.19 (7), R6.2
D7/RX: J1.1, J1.13 (1), U1.50 (U0RXD)
D8/A8/SCK: J1.2, J1.14 (2), J3.3, U1.12 (GPIO7)
D9/A9/MISO: J1.3, J1.15 (3), J3.4, U1.13 (GPIO8)
D10/A10/MOSI: J1.4, J1.16 (4), J3.5, U1.14 (GPIO9)
EN: C21.2, K1.1 (A0), K1.3 (A1), R8.1, TP6.T, U1.4 (CHIP_PU)
ESP_USB_D+: C1.2, R4.2, TP8.T, U1.26 (GPIO20)
ESP_USB_D-: C2.2, R3.2, TP7.T, U1.25 (GPIO19)
GND: ANT1.GND1, ANT1.GND2, C1.1, C2.1, C3.2, C4.2, C5.1, C6.1, C7.2, C8.1, C9.1, C10.2, C11.1, C12.1, C13.1, C14.1, C15.1, C16.1, C17.1, C18.1, C19.1, C20.1, C21.1, C22.1, C23.2, C25.2, C26.2, C28.1, C29.1, C30.1, GND0.1, J1.6, J1.18 (6), J3.1, J3.17, J3.28, J3.29, J3.31, J3.33, J3.34, K1.2 (B0), K1.4 (B1), K2.2 (B0), K2.4 (B1), R1.1, R2.2, R9.1, R10.1, R13.1, TP1.T, U1.57 (GND), U3.A1 (GND), U4.B1 (F), U4.C2 (GND), U5.4 (GND), USB0.A1_B12 (A1/B12/GND), USB0.B1_A12 (B1/A12/GND), USB0.S1, USB0.S2, USB0.S3, USB0.S4, USB0.S5 (S1), USB0.S6 (S2), X1.2 (GND), X1.4 (GND@1)
GND5: L4.1, U3.B2 (SW)
GND6: R13.2, U3.C1 (MODE)
GPIO0: C28.2, K2.1 (A0), K2.3 (A1), R7.1, U1.5 (GPIO0)
IO10/XMCLK: J3.6, U1.15 (GPIO10)
IO11/DVP_Y8: J3.7, U1.16 (GPIO11)
IO12/DVP_Y7: J3.8, U1.17 (GPIO12)
IO13/DVP_PCLK: J3.9, U1.18 (GPIO13)
IO14/DVP_Y6: J3.10, U1.19 (GPIO14)
IO15/DVP_Y2: J3.11, U1.21 (XTAL_32K_P)
IO16/DVP_Y5: J3.12, U1.22 (XTAL_32K_N)
IO17/DVP_Y3: J3.13, U1.23 (GPIO17)
IO18/DVP_Y4: J3.14, U1.24 (GPIO18)
IO21/USER_LED: D3.-, J3.16, U1.27 (GPIO21)
IO38/DVP_VSYNC: J3.23, U1.43 (GPIO38)
IO47/DVP_HREF: J3.22, U1.37 (SPICLK_P)
IO48/DVP_Y9: J3.21, U1.36 (SPICLK_N)
MTCK/IO39/CAM_SCL: J3.24, TP5.T, U1.44 (MTCK)
MTDI/IO41/PDM_DATA: J3.26, TP3.T, U1.47 (MTDI)
MTDO/IO40/CAM_SDA: J3.25, TP4.T, U1.45 (MTDO)
MTMS/IO42/PDM_CLK: J3.27, TP2.T, U1.48 (MTMS)
unnamed: R5.1, U1.54 (XTAL_P)
unnamed: C7.1, R5.2, X1.3 (X2)
unnamed: C8.2, U1.53 (XTAL_N), X1.1 (X1)
unnamed: ANT1.D, C17.2, L2.1, L3.2
unnamed: R2.1, USB0.B5 (B5/CC2)
unnamed: C15.2, L1.2, U1.2 (VDD3P3@1), U1.3 (VDD3P3@2)
unnamed: R1.2, USB0.A5 (A5/CC1)
unnamed: C18.2, L2.2, U1.1 (LNA_IN)
unnamed: CHG0.-, U4.B2 (NCHG)
unnamed: R6.1, U1.49 (U0TXD)
unnamed: R10.2, U4.C1 (IREF)
unnamed: CHG0.+, R11.2
unnamed: D3.+, R15.1
unnamed: C20.2, L3.1
SPICLK: U1.33 (SPICLK), U5.6 (CLK)
SPICS0: U1.32 (SPICS0), U5.1 (/CS)
SPID: U1.35 (SPID), U5.5 (DIO)
SPIHD: U1.30 (SPIHD), U5.7 (/HOLD)
SPIQ: U1.34 (SPIQ), U5.2 (DO)
SPIWP: U1.31 (SPIWP), U5.3 (/WP)
USB_D+: R4.1, USB0.A6 (A6/DP1), USB0.B6 (B6/DP2)
USB_D-: R3.1, USB0.A7 (A7/DN1), USB0.B7 (B7/DN2)
VBAT: BAT0.1, C26.1, Q1.1 (D), U4.A1 (BAT)
VBUS: C10.1, C25.1, D2.+, J1.7, J1.19 (7), Q1.2 (G), R9.2, R11.1, U4.A2 (VIN), USB0.A4_B9 (A4/B9/VBUS), USB0.B4_A9 (B4/A9/VBUS)
VCC_3V3: C5.2, C6.2, C9.2, C11.2, C12.2, C13.2, C14.2, C16.2, C19.2, C23.1, C29.2, J1.5, J1.17 (5), J3.18, J3.19, L1.1, L4.2, R7.2, R8.2, R15.2, U1.20 (VDD3P3_RTC), U1.46 (VDD3P3_CPU), U1.55 (VDDA@1), U1.56 (VDDA@2), U3.A2 (VOS)
VDD_SPI: C22.2, U1.29 (VDD_SPI), U5.8 (VCC)
VIN: C3.1, C4.1, C30.2, D2.-, J3.15, J3.30, Q1.3 (S), U3.B1 (VIN), U3.C2 (EN)

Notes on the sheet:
IO40
IO39
Π Type Impedance Matching
2.Adjust C30 and C16 inward
D0/A0/Qt1
DVP_Y7
Li Battery
IO5
External Flash
Optimize the distance from the positioning hole of the shield to the pads on both sides
DVP_Y3
D10/A10/Qt9/MOSI
0.3A/Pin
2023/1/4
LC Filter
IO1
D1/A1/Qt2
CAM
IO12
ESP32-S3
USB D+
Layout note： Bottom
D9/A9/Qt8/MISO
IO42
S3 IO20/D+
PDM_CLK
LCD
XIAO Header
v1.1
IO47
IO48
IO4
Camera
DVP_Y6
Internal PSRAM
IO21
IO11
BOOT
CAM_SCL
IO10



Board: 2 copper layers, 17.8 x 21.1 mm, 72 parts (11 on the bottom side), 62 nets.

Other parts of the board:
U$7: LOGO-SEEED-NEW-0.94X8.4MM

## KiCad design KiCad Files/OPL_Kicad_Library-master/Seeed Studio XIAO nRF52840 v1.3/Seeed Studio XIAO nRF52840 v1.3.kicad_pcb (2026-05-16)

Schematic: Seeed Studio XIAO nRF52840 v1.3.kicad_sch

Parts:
ANT1: ANTENNA-AN3216; ANT-SMD3P-3.2X1.6X1.04MM
BAT0: TEST-POINT'4080'; TP-80X40MIL
C1, C5, C8, C24, C34: 100nF; C0201
C2, C7: 10pF; C0201
C3, C4, C6, C9, C22, C25, C29, C30, C39, C41, C42: 2.2uF; C0201
C10: 1nF; C0402
C11: 1pF; C0201
C31: 820pF; C0201
C32, C33: 15pF; C0201
C35: 100pF; C0201
C36: 0.8pF; C0201
C37: 0.5pF; C0201
C38: 4.7nH; L0201
C40: DNP; C0201
CHG0: RED; LED-0402
D1: DIODE'0603'; SOD-523
GND0: GND; TP-80X40MIL
J1, J2: DNP; H7-HALF-HOLE-2.54
K1: BUTTON-4P; SW4-SMD-2.8-2.6X1.6X0.53MM
L3: 10uH; L0603
MIC1: MSM261D3526H1CPM; MIC6P-3.5X2.65X0.94MM
NFC1, NFC2: TEST-POINT'4080'; TP-80X40MIL
Q1: PMOS_1.00.60.35MM; PMOS_1.0_0.6_0.35MM
R1, R2: 5.1k; R0201
R3, R5, R7: 2.2k; R0201
R4, R13, R14, R15, R20: 10k; R0201
R9: 100k; R0201
R10, R11: 33R; R0201
R12, R18: 2.7k; R0201
R16: 1M_1%; R0201
R17: 510k_1%; R0201
RGB6: RGB; 4P1010
TP1, TP2, TP3, TP5: TEST-POINT'4545'; TP-D45MIL
U1: NRF52840_QF; AQFN50P700X700X85_HS-74N
U2: BQ25100; BQ25101_DSBGA_6_BQ25101
U3: LSM6DS3TR-C; LGA14-0.5-2.5X3X0.86MM
U6: 3.3V; X2SON-4
U7: DNP; USON2X3_8
USB1: USB2.0-TYPE-C
X1: 32.768KHz; X2-SMD-L1.6X1.0X0.5MM
X2: 32MHz; 4P1612

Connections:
3V3: C3.2, C6.2, C29.2, C39.1, C41.2, J1.5, J1.17 (5), R5.1, R13.1, RGB6.+, U1.A22 (VDD@A22), U1.AD14 (VDD@AD14), U1.AD23 (VDD@AD23), U1.B1 (VDD@B1), U1.W1 (VDD@W1), U1.Y2 (VDDH@Y2), U6.1 (OUT), U7.8 (VCC)
6D_INT1: U1.T2 (P0.11@T2), U3.4 (INT1)
6D_PWR: C1.2, R14.1, R15.1, U1.P2 (P1.08@P2), U3.5 (VDDIO), U3.8 (VDD), U3.12 (CS)
/CE: R20.1, U2.B1 (TS)
DEC4-6: C34.1, C42.1, L3.2, U1.B5 (DEC4@B5), U1.E24 (DEC6@E24)
GND: ANT1.2 (GND), C1.1, C2.1, C3.1, C4.2, C5.2, C6.1, C7.1, C8.1, C9.1, C10.2, C11.1, C22.1, C24.1, C25.1, C29.1, C30.2, C31.2, C32.2, C33.2, C34.2, C35.2, C36.1, C37.1, C39.2, C40.2, C41.1, C42.2, GND0.1, J1.6, J1.18 (6), K1.2 (B0), K1.4 (B1), MIC1.4 (GND@1), MIC1.5 (L/R), MIC1.6 (GND@2), R1.2, R2.1, R9.1, R18.2, R20.2, TP1.T, U1.B7 (VSS@B7), U1.F23 (VSS_PA@F23), U1.G74 (VSS_PAD), U2.C2 (VSS), U3.1 (SDO/DA0), U3.2 (SDX), U3.3 (SCX), U3.6 (GND@1), U3.7 (GND@2), U6.2 (GND), U6.T (GND), U7.4 (GND), U7.PAD (T), USB1.A1_B12 (A1/B12/GND), USB1.B1_A12 (B1/A12/GND), USB1.S1, USB1.S2, USB1.S3, USB1.S4, USB1.S5 (S1), USB1.S6 (S2), X2.2 (1), X2.4 (3)
INTERNAL_I2C_SCL: R14.2, U1.H2 (P0.27@H2), U3.13 (SCL)
INTERNAL_I2C_SDA: R15.2, U1.M2 (P0.07@M2), U3.14 (SDA)
unnamed: R1.1, USB1.A5 (A5/CC1)
unnamed: R2.2, USB1.B5 (B5/CC2)
unnamed: C2.2, U1.D2 (P0.00/XL1@D2), X1.2
unnamed: C7.2, U1.F2 (P0.01/XL2@F2), X1.1
unnamed: R7.1, RGB6.R-
unnamed: R4.1, RGB6.G-
unnamed: R10.2, U1.AD4 (D-@AD4)
unnamed: R11.2, U1.AD6 (D+@AD6)
unnamed: R3.1, RGB6.B-
unnamed: CHG0.+, R5.2
unnamed: ANT1.3, C10.1
unnamed: R12.1, R18.1, U2.B2 (ISET)
unnamed: C22.2, U1.AC5 (DECUSB@AC5)
unnamed: C24.2, U1.C1 (DEC1@C1)
unnamed: C31.1, U1.N24 (DEC5@N24)
unnamed: C33.1, U1.B24 (XC1@B24), X2.1 (2)
unnamed: C32.1, U1.A23 (XC2@A23), X2.3 (4)
unnamed: C35.1, U1.D23 (DEC3@D23)
unnamed: C36.2, C38.1, U1.H23 (ANT@H23)
unnamed: ANT1.1 (S), C37.2, C38.2
unnamed: C40.1, U1.A18 (DEC2@A18)
unnamed: L3.1, U1.B3 (DCC@B3)
P0.02_AIN0_LOW_A0_D0: J2.1, J2.13 (1), U1.A12 (P0.02/AIN0@A12)
P0.03_AIN1_LOW_A1_D1: J2.2, J2.14 (2), U1.B13 (P0.03/AIN1@B13)
P0.04_AIN2_A4_D4: J2.5, J2.17 (5), U1.J1 (P0.04/AIN2@J1)
P0.05_AIN3_A5_D5: J2.6, J2.18 (6), U1.K2 (P0.05/AIN3@K2)
P0.06_USER_BLUE: R3.2, U1.L1 (P0.06@L1)
P0.09/NFC1: NFC1.1, U1.L24 (P0.09/NFC1@L24)
P0.10/NFC2: NFC2.1, U1.J24 (P0.10/NFC2@J24)
P0.13_HICHG: R12.2, U1.AD8 (P0.13@AD8)
P0.14_~READ_BAT: R17.2, U1.AC9 (P0.14@AC9)
P0.16_PDM_DATA: MIC1.3 (DATA), U1.AC11 (P0.16@AC11)
P0.17_~CHG: CHG0.-, U1.AD12 (P0.17@AD12), U2.C1 (PRETERM)
P0.20_QSPI_SIO_0: U1.AD16 (P0.20@AD16), U7.5 (DI)
P0.21_QSPI_SCK: C11.2, U1.AC17 (P0.21@AC17), U7.6 (CLK)
P0.22_QSPI_SIO_2: U1.AD18 (P0.22@AD18), U7.3 (~WP)
P0.23_QSPI_SIO_3: U1.AC19 (P0.23@AC19), U7.7 (~HOLD)
P0.24_QSPI_SIO_1: U1.AD20 (P0.24@AD20), U7.2 (DO)
P0.25_QSPI_CSN: U1.AC21 (P0.25@AC21), U7.1 (~CS)
P0.26_USER_RED: R7.2, U1.G1 (P0.26@G1)
P0.28_AIN4_LOW_A2_D2: J2.3, J2.15 (3), U1.B11 (P0.28/AIN4@B11)
P0.29_AIN5_LOW_A3_D3: J2.4, J2.16 (4), U1.A10 (P0.29/AIN5@A10)
P0.30_USER_GREEN: R4.2, U1.B9 (P0.30/AIN6@B9)
P0.31_AIN7_BAT: R16.2, R17.1, U1.A8 (P0.31/AIN7@A8)
P1.00_PDM_CLK: MIC1.2 (CLK), U1.AD22 (P1.00@AD22)
P1.10_MIC_PWR: C8.2, MIC1.1 (VDD), U1.A20 (P1.10@A20)
P1.11_TX_D6: J2.7, J2.19 (7), U1.B19 (P1.11@B19)
P1.12_RX_D7: J1.1, J1.13 (1), U1.B17 (P1.12@B17)
P1.13_SCK_D8: J1.2, J1.14 (2), U1.A16 (P1.13@A16)
P1.14_MISO_D9: J1.3, J1.15 (3), U1.B15 (P1.14@B15)
P1.15_MOSI_D10: J1.4, J1.16 (4), U1.A14 (P1.15@A14)
PWR_LED: U1.R24 (P1.06@R24)
RESET: C5.1, K1.1 (A0), K1.3 (A1), R13.2, TP2.T, U1.AC13 (P0.18/RESET@AC13)
SWDCLK: TP3.T, U1.AA24 (SWDCLK@AA24)
SWDIO: TP5.T, U1.AC24 (SWDIO@AC24)
USB_D+: R11.1, USB1.A6 (A6/DP1), USB1.B6 (B6/DP2)
USB_D-: R10.1, USB1.A7 (A7/DN1), USB1.B7 (B7/DN2)
VBAT: BAT0.1, C30.1, Q1.1 (D), R16.1, U2.A1 (OUT)
VBUS: C9.2, C25.2, D1.+, J1.7, J1.19 (7), Q1.2 (G), R9.2, U1.AD2 (VBUS@AD2), U2.A2 (IN), USB1.A4_B9 (A4/B9/VBUS), USB1.B4_A9 (B4/A9/VBUS)
VIN: C4.1, D1.-, Q1.3 (S), U6.3 (EN), U6.4 (IN)

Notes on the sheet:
Linus.Liao
2.Change C32,C33 to 15pF
zhihuai.Zhou
Initail Version
the TS and VSS.
NTC:
2021.2.2
Set P0.14 to output Sink only to enable BAT voltage read;
v1.0
2.Add C11 to to resolve the issue of data corruption during Flash read operations.
1.Change 32M Crystal
Disable Temp sense function,
2025.6.20
1.Remove R8
use fixed 10k resistor between
2024.3.19

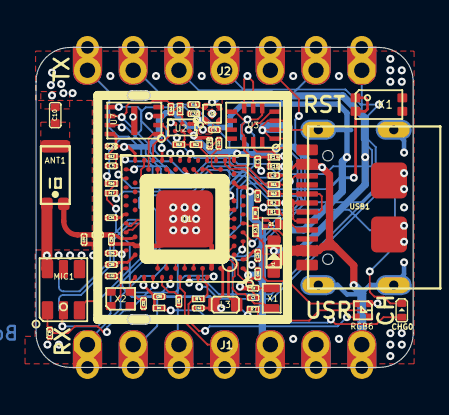
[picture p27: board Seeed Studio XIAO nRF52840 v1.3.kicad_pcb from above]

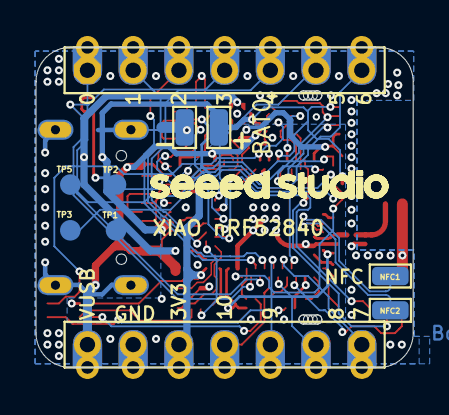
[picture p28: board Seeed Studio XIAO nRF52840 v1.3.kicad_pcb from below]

Board: 2 copper layers, 21.0 x 17.8 mm, 80 parts (9 on the bottom side), 67 nets.

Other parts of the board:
U$14: LOGO-SEEED-NEW-1_3X13MM
UNK_HOLE_0: dummyfp0
UNK_HOLE_1: dummyfp1
UNK_HOLE_2: dummyfp2
UNK_HOLE_3: dummyfp3
UNK_HOLE_4: dummyfp4
UNK_HOLE_5: dummyfp5
UNK_HOLE_6: dummyfp6
UNK_HOLE_7: dummyfp7

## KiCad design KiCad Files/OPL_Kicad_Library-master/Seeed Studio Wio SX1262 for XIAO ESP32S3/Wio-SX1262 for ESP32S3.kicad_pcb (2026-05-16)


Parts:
C1: 100nF; C0402; Voltage Rating 16V,X7R; MPN CC0402KRX7R7BB104
D1: Green; LED-0603; MPN 19-217/G7C-AN1P2/3T
J1, J2: Header 1x7 2.54mm; H7-2.54; Part Type Header
J3: 30pin; BTB2X15-FEMALE-8.6X2.94X3.9MM; Rating DC0.3A; MPN BTB SCOKET P0.40
K1: TS-1185E; BUTTON2P_3_9X3X2MM; MPN TS-1185E
R1, R3: 10K; R0402; Power Rating 5%; MPN RC0402JR-0710KL
R2: 330R; R0402; Power Rating 1%; MPN RC0402FR-07330RL
R4, R5, R6, R7: 47R; R0402; Power Rating 1%; MPN RC0201FR-0745RL
TP1: Test Point; TP-D3_5c2_2mm; Part Type Test Point
U1: Wio-SX1262; MODULE12P-1.27-11X11.6MM; MPN Wio-SX1262

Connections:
+3V3: C1.1, J2.3, J3.23, J3.25, R1.2, R3.2, U1.8 (VCC)
GND: C1.2, J2.2, J3.2, J3.3, J3.5, J3.27, K1.1, R2.1, U1.7 (GND1), U1.10 (GND2)
GPIO14: J3.20
GPIO15: J3.22
GPIO16: J3.24
GPIO17: J3.26
GPIO18: J3.28
GPIO21: J3.29, K1.2, R3.1
GPIO47: J3.17
GPIO48: D1.1 (+), J3.19
LORA_BUSY: J1.2, J3.11, U1.11 (BUSY)
LORA_DIO1: J1.1, J3.13, U1.12 (DIO1)
LORA_RF_SW1: J1.5, J3.15, U1.1 (RF_SW1)
LORA_RST: J1.3, J3.7, R1.1, U1.5 (RST)
LORA_SPI_MISO: J2.5, J3.8, R4.1
LORA_SPI_MOSI: J2.4, J3.10, R5.1
LORA_SPI_NSS: J1.4, J3.9, R7.1
LORA_SPI_SCK: J2.6, J3.6, R6.1
unnamed: D1.2 (-), R2.2
unnamed: R4.2, U1.2 (MISO)
unnamed: R5.2, U1.3 (MOSI)
unnamed: R7.2, U1.6 (NSS)
unnamed: R6.2, U1.4 (SCK)
VIN: J2.1, J3.1, J3.30

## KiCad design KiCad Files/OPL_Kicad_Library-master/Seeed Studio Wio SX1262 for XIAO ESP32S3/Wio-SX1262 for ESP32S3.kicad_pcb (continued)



Board: 2 copper layers, 17.8 x 21.4 mm, 15 parts (5 on the bottom side), 18 nets.

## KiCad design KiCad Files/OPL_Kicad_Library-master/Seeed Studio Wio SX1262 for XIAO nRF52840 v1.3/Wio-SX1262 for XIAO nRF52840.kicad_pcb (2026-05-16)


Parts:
C1: 100nF; C0402; Voltage Rating 16V,X7R; MPN CC0402KRX7R7BB104
J1, J2: Header 1x7 2.54mm; H7-2.54; Part Type Header
K1: TS-1188E 6C81; SW4-SMD-7.0X3.5X3.5MM-90D; MPN TS-1188E 6C81; not fitted
R1: 10K; R0402; Power Rating 5%; MPN RC0402JR-0710KL
R2: 10K; R0402; Power Rating 5%; MPN RC0402JR-0710KL; not fitted
R3, R4, R5, R6: 22R; R0402; Power Rating 1%; MPN RC0402FR-0722RL
U1: Wio-SX1262; MODULE12P-1.27-11X11.6MM; MPN Wio-SX1262

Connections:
+3V3: C1.1, J2.3, R1.2, R2.2, U1.8 (VCC)
/D0: J1.1, K1.2, R2.1
/LORA_BUSY: J1.4, U1.11 (BUSY)
/LORA_DIO1: J1.2, U1.12 (DIO1)
/LORA_RF_SW1: J1.6, U1.1 (RF_SW1)
/LORA_RST: J1.3, R1.1, U1.5 (RST)
/LORA_SPI_MISO: J2.5, R4.1
/LORA_SPI_MOSI: J2.4, R5.1
/LORA_SPI_NSS: J1.5, R3.1
/LORA_SPI_SCK: J2.6, R6.1
GND: C1.2, J2.2, K1.1, K1.3 (S1), K1.4 (S2), U1.7 (GND1), U1.10 (GND2)
unnamed: R4.2, U1.2 (MISO)
unnamed: R5.2, U1.3 (MOSI)
unnamed: R3.2, U1.6 (NSS)
unnamed: R6.2, U1.4 (SCK)
VIN: J2.1


Board: 2 copper layers, 17.8 x 21.4 mm, 11 parts (0 on the bottom side), 15 nets.

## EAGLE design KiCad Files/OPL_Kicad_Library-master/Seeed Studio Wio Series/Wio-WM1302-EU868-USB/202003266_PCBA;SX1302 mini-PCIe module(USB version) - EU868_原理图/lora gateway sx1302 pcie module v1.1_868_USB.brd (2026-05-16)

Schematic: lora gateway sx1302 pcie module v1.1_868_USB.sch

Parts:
ANT1: U.FL-R-SMT-1(10); U-FL3P-SMD-2.6X2.6X1.0MM
ANT2: DNP; U-FL3P-SMD-2.6X2.6X1.0MM
C1, C12, C15, C19, C23, C25, C26, C29, C32, C41, C43, C45, C65, C67, C80, C83, C86, C88: 100nF; C0402
C2, C75: 2.2pF; C0402
C3, C92: 10uF; C0603
C4, C8, C11, C16, C17, C18, C64: 56pF; C0402
C5, C6, C9, C10: 3.6pF; C0402
C7, C91: 5.6pF; C0402
C13, C20, C21, C24, C28, C35, C39, C40, C42, C44, C47, C48, C76, C87, C89: 1uF; C0402
C14, C38, C57, C66, C81, C84: 10pF; C0402
C22, C27, C33: 10uF; C0603@1
C30, C56, C74, C77, C78, C79: DNP; C0402
C31: DNP; C0603@1
C34, C46, C63: 470nF; C0402
C36: 47nF; C0402
C37: 47pF; C0402
C49: 4.7uF; C0603
C50, C62, C85: 10nF; C0402
C51: 1nF; C0402
C52, C55: 100pF; C0402
C53, C60, C61: 3.3pF; C0402
C54: 39pF; C0402
C58: 1.3pF; C0402
C59, C68, C73: 1.8pF; C0402
C69, C70, C71, C72: 10uF; C0805
C82: 2.7pF; C0402
C90: 2.2uF; C0603
D1, D4: Green; LED-0402
D2: Red; LED-0402
D3: Blue; LED-0402
D5: LXES15AAA1-153; ESD-0402
D6: DNP; ESD-0402
D7: BAT54XV2T1G; SOD-523
FB1: BLM15PD121SN1D; F0402
J1: DNP; PCIE52P-0.8-50.95X30MM
L1: LQP15MN1N2B02D; L0402
L2: LQW15AN6N8G00D; L0402
L4: 0R; F0603
L5: LQH44PN1R0NP0L; L4.4X3.0MM
L6, L14, L20: MLZ2012M150WT; L0805
L7, L15, L18, L21: DNP; L0402
L8: LQW15AN3N0B00; L0402
L9: LQW15AN47NJ00D; L0402
L10: LQW15AN2N5B00D; L0402
L11: LQW15AN4N7C00D; L0402
L12, L13: LQW15AN12NG00D; L0402
L16: LQW15AN7N5G00D; L0402
L17, L24: LQW15AN5N6C10D; L0402
L22: LQW15AN15NG00D; L0402
Q8: CJ2101; SOT-323
Q10: CJ2102; SOT-323
R1, R4, R33, R34, R38, R42, R57, R65, R71: 10k; R0402
R2, R7: 0R; R0603
R3, R8, R11, R12, R43, R44, R46, R49, R51, R55, R56, R59, R60, R61, R62, R63, R67, R70, R72, R73, R74, R75, R76, R81: DNP; R0402
R5, R10, R14, R15, R16, R39, R40, R41: 100R; R0402
R6, R9, R37: 220R; R0402
R13, R35, R52: DNP; R0603
R17, R18, R19, R20, R21, R22, R23, R24, R25, R26, R27, R28, R29, R36, R45, R48, R50, R53, R54, R69, R77: 0R; R0402
R30, R31, R32: 680R; R0402
R47, R79: 1k; R0402
R58, R68: 4.7k; R0402
R64, R66: 22R; R0402
R78, R82: 100k; R0402
R80: 10R; R0402
R83, R87: 200k_1%; R0402
S1, S2, S3, S4, S5, S6: 323030226; SHIELD_CLIP
TP1, TP2, TP3, TP4, TP5, TP6, TP7, TP8, TP9, TP10, TP14: TEST-POINT-35; TP_3535
TP15: TEST-POINT'4545'; TP-D45MIL
U1: SX1302IMLTRT; QFN68-0.35-7X7X0.75MM
U2, U8, U10: HDF866A3-S6; FILTER6P-1.1-3X3X1.3MM
U3, U4: DNP; SOT-23-5
U5, U7: SX1250IMLTRT; QFN24G-0.5-4X4MM
U6: MP2161GJ; TSOT23-8
U9: SKY66420-11; MODULE16P-0.5-3X3X0.75MM
U11: SX1262IMLTRT; QFN24G-0.5-4X4MM
U12: STM32L412K8U6; UFQFPN32-0.5-5X5MM
U13: STTS751; UDFN-6L
X1: DSB221SDN; X4-SMD-2.5X2.0X1.0MM
X3: 32.768kHz; X2-SMD-3.2X1.5X0.55MM

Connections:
32MHZ: R6.2, R9.2, R37.2, X1.3 (OUT)
1302_CS: R33.2, R43.1, U1.1 (HOST_CSN), U12.10 (PA4)
1302_RESET: C1.2, D7.-, R1.2, U1.7 (RESET), U12.8 (PA2)
1302_RESET_HOST: D7.+, R59.1
CONFIG_OK: R31.1, U1.66 (GPIO0)
DM: J1.36, R66.1
DP: J1.38, R64.1
FEM_CS: R14.2, R34.1, U1.10 (RADIO_CTRL0), U3.3 (CE)
FEM_PA_ON: R15.2, U1.16 (RADIO_CTRL4)
GND: ANT1.GND1, ANT1.GND2, ANT2.GND1, ANT2.GND2, C2.1, C3.1, C5.1, C7.1, C9.1, C12.1, C13.1, C15.1, C16.1, C17.1, C18.1, C19.1, C20.1, C21.1, C22.1, C23.1, C24.1, C25.1, C26.1, C27.1, C28.1, C29.1, C30.1, C31.1, C32.1, C33.1, C34.1, C35.1, C36.1, C37.1, C39.1, C40.1, C41.1, C42.1, C43.1, C44.1, C45.1, C46.1, C47.1, C48.1, C49.1, C50.1, C51.1, C52.1, C55.1, C56.1, C57.1, C58.1, C60.2, C61.2, C62.1, C63.2, C65.2, C67.2, C69.1, C70.1, C71.1, C72.1, C73.2, C74.2, C76.1, C77.2, C78.2, C80.1, C81.2, C82.2, C83.1, C84.2, C85.1, C86.1, C87.1, C88.1, C89.1, C90.1, C92.1, D1.-, D2.-, D3.-, D4.-, D5.1, D6.1, J1.4 (GND), J1.9 (GND), J1.15 (GND), J1.18 (GND), J1.21 (GND), J1.26 (GND), J1.27 (GND), J1.29 (GND), J1.34 (GND), J1.35 (GND), J1.37 (GND), J1.40 (GND), J1.43 (GND), J1.50 (GND), J1.S1 (GND), J1.S2 (GND), Q10.2 (S), R1.1, R4.1, R11.1, R12.1, R17.2, R53.1, R53.2, R54.1, R54.2, R55.1, R55.2, R57.2, R73.1, R74.1, R74.2, R87.1, S1.S1, S1.S2, S1.S3, S1.S4, S1.S5, S2.S1, S2.S2, S2.S3, S2.S4, S2.S5, S3.S1, S3.S2, S3.S3, S3.S4, S3.S5, S4.S1, S4.S2, S4.S3, S4.S4, S4.S5, S5.S1, S5.S2, S5.S3, S5.S4, S5.S5, S6.S1, S6.S2, S6.S3, S6.S4, S6.S5, TP3.T, U1.6 (GND), U1.9 (GND), U1.15 (GND), U1.24 (GND), U1.25 (GND), U1.39 (GND), U1.46 (GND), U1.55 (GND), U1.62 (GND), U1.69 (GND), U2.1 (GND), U2.3 (GND), U2.4 (GND), U2.6 (GND), U3.2 (VSS), U4.2 (VSS), U5.7 (GND), U5.20 (GND), U5.PAD, U6.4 (PGND), U6.6 (AGND), U7.7 (GND), U7.20 (GND), U7.PAD, U8.1 (GND), U8.3 (GND), U8.4 (GND), U8.6 (GND), U9.10 (GND), U9.12 (GND), U9.17 (EPAD), U10.1 (GND), U10.3 (GND), U10.4 (GND), U10.6 (GND), U11.2 (GND), U11.5 (GND), U11.8 (GND), U11.20 (GND), U11.PAD, U12.16 (VSS), U12.32 (VSS), U12.PAD, U13.4 (ADDR/!THERM), U13.5 (GND), X1.2 (GND)
HOST_CS0: J1.51, R43.2
HOST_CS1: J1.25, R51.2
HOST_IO1: J1.33, R61.2
HOST_IO2: J1.31, R63.2
HOST_IO3: J1.23
HOST_IO4: J1.8, R67.2
HOST_IO5: J1.10, R60.2
HOST_IO6: J1.12
HOST_MISO: R39.1, R44.2
HOST_MOSI: J1.49, R46.2
HOST_RST: J1.22, R59.2, R77.2
HOST_SCK: J1.45, R49.2
I2C_SCL: R68.2, R76.1, R81.1, U12.29 (PB6), U13.1 (SCL)
I2C_SDA: R58.2, R70.1, R75.1, U12.30 (PB7), U13.6 (SDA)
MCU_RESET: C85.2, R71.2, R77.1, TP5.T, U12.4 (NRST)
MISO: R44.1, R45.1, U1.2 (HOST_MISO), U11.16 (MISO)
MISO_A: U1.42 (RADIO_A_MISO), U5.16 (MISO)
MISO_B: U1.33 (RADIO_B_MISO), U7.16 (MISO)
MOSI: R5.2, R40.2, R46.1, R48.1
MOSI_A: U1.67 (RADIO_A_MOSI), U5.17 (MOSI)
MOSI_B: U1.19 (RADIO_B_MOSI), U7.17 (MOSI)
unnamed: C11.2, U9.2 (RX)
unnamed: TP15.T, U6.1 (PG)
unnamed: C8.1, R11.2, R52.2, U8.5 (OUT)
unnamed: C2.2, L11.2, R52.1, U8.2 (IN)
unnamed: C11.1, R13.2, U2.2 (IN)
unnamed: C4.2, U9.1 (TX)
unnamed: C68.1, C74.1, C75.2
unnamed: C65.1, L18.2, R36.2, U11.1 (VDD_IN)
unnamed: C66.2, R37.1
unnamed: L5.1, U6.3 (SW)
unnamed: R83.1, R87.2, U6.7 (FB)
unnamed: R3.1, R4.2, X1.1 (ENABLE)
unnamed: C14.1, U5.3 (XTA)
unnamed: C62.2, L4.1, R3.2, X1.4 (VDD)
unnamed: R5.1, U1.3 (HOST_MOSI)
unnamed: D4.+, R47.2
unnamed: R10.1, U1.4 (HOST_SCK)
unnamed: R82.2, U6.8 (EN)
unnamed: R8.1, U4.3 (CE)
unnamed: C14.2, R6.1
unnamed: L6.2, U5.8 (DCC_SW)
unnamed: C34.2, L6.1, L7.2, U5.6 (VREG)
unnamed: C64.1, C82.1, L24.2
unnamed: R19.1, U1.34 (RADIO_B_CLK_I)
unnamed: C16.2, R14.1, U9.4 (CSD)
unnamed: C38.1, U7.3 (XTA)
unnamed: C36.2, C37.2, L9.2, U5.1 (VR_PA)
unnamed: C38.2, R9.1
unnamed: L14.2, U7.8 (DCC_SW)
unnamed: C46.2, L14.1, L15.2, U7.6 (VREG)
unnamed: C54.2, L11.1
unnamed: C7.2, C53.2, C54.1, L10.2
unnamed: C4.1, C8.2, R12.2
unnamed: C17.2, R15.1, U9.5 (CPS)
unnamed: C18.2, R16.1, U9.6 (CTX)
unnamed: R17.1, U1.20 (SP_VALID)
unnamed: R18.1, U1.32 (RADIO_B_IQ3)
unnamed: R20.1, U1.35 (RADIO_B_IQ0)
unnamed: R24.1, U1.41 (RADIO_A_IQ3)
unnamed: R21.1, U1.36 (RADIO_B_IQ1)
unnamed: R22.1, U1.37 (RADIO_B_IQ4)
unnamed: R23.1, U1.38 (RADIO_B_IQ2)
unnamed: R25.1, U1.43 (RADIO_A_CLK_I)
unnamed: R26.1, U1.44 (RADIO_A_IQ0)
unnamed: R27.1, U1.45 (RADIO_A_IQ1)
unnamed: R28.1, U1.48 (RADIO_A_IQ4)
unnamed: R29.1, U1.49 (RADIO_A_IQ2)
unnamed: D3.+, R32.2
unnamed: D2.+, R31.2
unnamed: D1.+, R30.2
unnamed: Q8.1 (G), Q10.3 (D), R78.2
unnamed: C1.1, R80.1
unnamed: L1.1, U9.16 (VCC1)
unnamed: L2.1, L8.1, U9.13 (PA_OUT)
unnamed: C56.2, C57.2, L8.2, L16.1
unnamed: C58.2, L16.2, U9.11 (TX_IN)
unnamed: C59.2, C60.1, L17.1, U9.9 (ANT)
unnamed: C61.1, C91.1, L17.2, L24.1
unnamed: C66.1, U11.3 (XTA)
unnamed: ANT1.D, C64.2, D5.2
unnamed: R35.2, R62.1, R69.2, U10.2 (IN)
unnamed: C63.1, L18.1, L20.1, U11.7 (VREG)
unnamed: R35.1, U9.7 (LNA_IN), U10.5 (OUT)
unnamed: L20.2, U11.9 (DCC_SW)
unnamed: J1.47, R39.2
unnamed: R40.1, U11.17 (MOSI)
unnamed: R41.1, U11.18 (SCK)
unnamed: C6.1, C10.1, C75.1, R13.1, U2.5 (OUT)
unnamed: R69.1, U9.8 (RX_FLT)
unnamed: C78.1, C79.1, L21.2
unnamed: ANT2.D, C79.2, D6.2
unnamed: C59.1, C91.2
unnamed: C77.1, L21.1, R62.2
unnamed: R65.2, U13.2 (!EVENT)
unnamed: C52.2, FB1.1, L1.2, U9.15 (VCC0)
unnamed: R64.2, U12.22 (PA12)
unnamed: R66.2, U12.21 (PA11)
unnamed: C92.2, Q10.1 (G), R79.2
unnamed: R56.2, R57.1, U12.31 (BOOT0)
unnamed: R72.2, R73.2, U12.6 (PA0-CLK_IN)
unnamed: C81.1, U12.2 (PC14-OSC32_IN), X3.2
unnamed: C84.1, U12.3 (PC15-OSC32_OUT), X3.1
unnamed: J1.14, R76.2
unnamed: J1.16, R70.2
unnamed: J1.30, R81.2
unnamed: J1.32, R75.2
PPS: J1.19, TP2.T, U1.8 (PPS), U12.27 (PB4)
RADIO_A_CLK_32M: R25.2, R72.1, U5.14 (BUSY)
RADIO_A_CLK_O: R28.2, U5.11 (DIO5)
RADIO_A_CSN: U1.68 (RADIO_A_CSN), U5.19 (NSS)
RADIO_A_IQ_0: R26.2, U5.13 (DIO1)
RADIO_A_IQ_1: R27.2, U5.12 (DIO2)
RADIO_A_IQ_2: R29.2, U5.5 (DIO3)
RADIO_A_IQ_3: R24.2, U5.21 (DIO4)
RADIO_A_RESET: U1.13 (RADIO_CTRL3), U5.15 (NRESET)
RADIO_A_RFIN: C6.2, L12.2, U5.23 (RFI_N)
RADIO_A_RFIP: C5.2, L12.1, U5.22 (RFI_P)
RADIO_B_CLK_32M: R19.2, U7.14 (BUSY)
RADIO_B_CLK_O: R22.2, U7.11 (DIO5)
RADIO_B_CSN: U1.18 (RADIO_B_CSN), U7.19 (NSS)
RADIO_B_IQ0: R20.2, U7.13 (DIO1)
RADIO_B_IQ_1: R21.2, U7.12 (DIO2)
RADIO_B_IQ_2: R23.2, U7.5 (DIO3)
RADIO_B_IQ_3: R18.2, U7.21 (DIO4)
RADIO_B_RESET: U1.28 (RADIO_CTRL9), U7.15 (NRESET)
RADIO_B_RFIN: C10.2, L13.2, U7.23 (RFI_N)
RADIO_B_RFIP: C9.2, L13.1, U7.22 (RFI_P)
RFO: C53.1, L9.1, L10.1, U5.24 (RFO)
RX_ON: R32.1, U1.59 (GPIO4)
SCK: R10.2, R41.2, R49.1, R50.1
SCK_A: U1.65 (RADIO_A_SCK), U5.18 (SCK)
SCK_B: U1.21 (RADIO_B_SCK), U7.18 (SCK)
STM32_MISO: R45.2, U12.12 (PA6)
STM32_MOSI: R48.2, U12.13 (PA7)
STM32_SCK: R50.2, U12.11 (PA5)
SWCLK: TP7.T, U12.24 (PA14)
SWDIO: TP8.T, U12.23 (PA13)
SX1261_BUSY: R67.1, U11.14 (BUSY), U12.9 (PA3)
SX1261_CS: R42.1, R51.1, U11.19 (NSS), U12.14 (PB0)
SX1261_IO1: R61.1, U1.54 (GPIO7), U11.13 (DIO1), U12.15 (PB1)
SX1261_IO2: R63.1, U11.12 (DIO2)
SX1261_IO3: TP9.T, U11.6 (DIO3)
SX1261_RFIN: C68.2, L22.2, U11.22 (RFI_N)
SX1261_RFIP: C73.1, L22.1, U11.21 (RFI_P)
SX1261_RST: R38.1, R60.1, U11.15 (NRESET), U12.18 (PA8)
SX1302_GPIO8: U1.53 (GPIO8), U12.26 (PB3)
TX_ON: R30.1, U1.63 (GPIO2)
TX_RX_SW: R16.2, U1.12 (RADIO_CTRL2)
VCCIO: C3.2, C19.2, C20.2, C25.2, C28.2, C41.2, C42.2, C45.2, C47.2, C76.2, C80.2, C83.2, C86.2, C87.2, C88.2, C89.2, C90.2, Q8.3 (D), R33.1, R34.2, R56.1, R58.1, R65.1, R68.1, R71.1, R80.2, TP1.T, U1.14 (VCC_IO), U1.30 (VCC_IO), U1.47 (VCC_IO), U1.61 (VCC_IO), U12.1 (VDD), U12.5 (VDDA), U12.17 (VDD), U13.3 (VDD)
VCC_1V2: C12.2, C13.2, C23.2, C24.2, C29.2, C40.2, C43.2, C44.2, C71.2, C72.2, L5.2, R79.1, R83.2, TP14.T, U1.5 (VCC_CORE), U1.23 (VCC_CORE), U1.40 (VCC_CORE), U1.56 (VCC_CORE), U6.5 (OUT)
VCC_FEM: C26.2, C27.2, C49.2, C50.2, C51.2, C55.2, FB1.2, L2.2, R2.2, TP6.T, U3.5 (VOUT)
VCC_RADIO: C21.2, C32.2, C33.2, C35.2, C39.2, C48.2, C67.1, L4.2, L7.1, L15.1, R7.2, R36.1, R38.2, R42.2, TP10.T, U4.5 (VOUT), U5.2 (VDD_IN), U5.9 (VBAT_RF), U5.10 (VBAT_DIO), U7.2 (VDD_IN), U7.9 (VBAT_RF), U7.10 (VBAT_DIO), U11.10 (VBAT), U11.11 (VBAT_IO)
VIN: C15.2, C22.2, C30.2, C31.2, C69.2, C70.2, J1.2 (3V3), J1.24 (3V3), J1.39 (3V3), J1.41 (3V3), J1.52 (3V3), Q8.2 (S), R2.1, R7.1, R8.2, R47.1, R78.1, R82.1, TP4.T, U3.1 (VIN), U4.1 (VIN), U6.2 (VIN)

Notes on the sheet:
V1.0
Initial Release
2020/01/02
Vincent
50ohm Impedence
3.3V
300mA
1.2V
500mA
100mA
USB
868
915
SPI
For Power-up delay
V1.1
Add power up delay circuit at VCCIO
Add power up reset circuit for SX1302
Change pins refer to Semtech V3 Schematic
2021/02/18



Board: 4 copper layers, 30.0 x 51.0 mm, 244 parts (68 on the bottom side), 162 nets.

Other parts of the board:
U$45: SEEED-SILK-TNAME-280*268MIL

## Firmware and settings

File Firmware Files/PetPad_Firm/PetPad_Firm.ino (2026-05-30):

// Buttons
#define BTN1 0 // SW1 -> MCU Pin 1 -> GPIO0
#define BTN2 1 // SW2 -> MCU Pin 2 -> GPIO1
#define BTN3 2 // SW3 -> MCU Pin 3 -> GPIO2

// I2C OLED
#define SDA_PIN 22 // OLED SDA -> MCU Pin -> GPIO22
#define SCL_PIN 23 // OLED SCL -> MCU Pin -> GPIO23

// Buzzer
#define BUZZER 18 // Buzzer Signal -> MCU Pin 11 -> GPIO18

// Includes and Hardware Config
#include <Wire.h>
#include <Adafruit_GFX.h>
#include <Adafruit_SSD1306.h>

#define SCREEN_WIDTH 128
#define SCREEN_HEIGHT 64
#define OLED_RESET -1

Adafruit_SSD1306 display(SCREEN_WIDTH, SCREEN_HEIGHT, &Wire, OLED_RESET);

#define BTN_LEFT D0
#define BTN_MIDDLE D1
#define BTN_RIGHT D2
#define BUZZER_PIN D10

struct Pet {
  int hunger; // 0 to 200 (0 = starving, 100 = full, 200 = overfed)
  int love; // 0 to 100 (0 = depressed, 25 = sad, 50 = neutral, 75 = happy, 100 = best day ever!)
  int energy; // 0 to 200 (0 = exhausted, 100 = full, 200 = hyper)
  int life; // -100 to 100 (-100 = undead, 0 = death imminent, 100 = healthy)
  unsigned long age; // total seconds Pet has lived
};

Pet pet;

enum Screen {
  SCREEN_MAIN,
  SCREEN_FEED,
  SCREEN_PLAY,
  SCREEN_SLEEP
};

Screen currentScreen = SCREEN_MAIN;

void logPetStats(const char* source) {
  Serial.print(source);
  Serial.print(": hunger="); Serial.print(pet.hunger);
  Serial.print(" love="); Serial.print(pet.love);
  Serial.print(" energy="); Serial.print(pet.energy);
  Serial.print(" life="); Serial.print(pet.life);
  Serial.print(" age="); Serial.println(pet.age);
}

void setup() {
  Serial.begin(115200);
  delay(10);
  Serial.println("PetPad: starting");

  pinMode(BTN_LEFT, INPUT_PULLUP);
  pinMode(BTN_MIDDLE, INPUT_PULLUP);
  pinMode(BTN_RIGHT, INPUT_PULLUP);
  pinMode(BUZZER_PIN, OUTPUT);

  Wire.begin(SDA_PIN, SCL_PIN);
  Serial.print("I2C pins SDA="); Serial.print(SDA_PIN);
  Serial.print(" SCL="); Serial.println(SCL_PIN);

  if (!display.begin(SSD1306_SWITCHCAPVCC, 0x3C)) {
    Serial.println("SSD1306 init FAILED");
  } else {
    Serial.println("SSD1306 init OK");
  }

  display.clearDisplay();
  display.setTextSize(1);
  display.setTextColor(SSD1306_WHITE);
  display.setCursor(0, 0);
  display.println("PetPad is loading...");
  display.display();
  delay(1000);

  pet.hunger = 80;
  pet.love = 50;
  pet.energy = 80;
  pet.life = 100;
  pet.age = 0;

  Serial.print("Initial pet: hunger="); Serial.print(pet.hunger);
  Serial.print(" love="); Serial.print(pet.love);
  Serial.print(" energy="); Serial.print(pet.energy);
  Serial.print(" life="); Serial.println(pet.life);
}

unsigned long lastUpdate = 0;

void updatePet() {
  if (millis() - lastUpdate > 5000) {
    pet.hunger--;
    pet.energy--;
    pet.love--;

    if (pet.hunger < 30 || pet.energy < 30 || pet.love < 30) {
      pet.life -= 5;
    } else if (pet.hunger > 150 || pet.energy > 150) {
      pet.life -= 5;
    } else if (pet.hunger > 70 && pet.energy > 70 && pet.love > 70) {
      pet.life += 5;
    } else {
      pet.life += 1;
    }

    if (pet.life > 100) pet.life = 100;
    if (pet.life < -100) pet.life = -100;
    if (pet.hunger < 0) pet.hunger = 0;
    if (pet.energy < 0) pet.energy = 0;
    if (pet.love < 0) pet.love = 0;

    pet.age += 5;
    lastUpdate = millis();
    logPetStats("Pet tick updated");
  }
}

unsigned long lastButtonPress = 0;

void checkButtons() {
  if (millis() - lastButtonPress < 200) return;
  if (digitalRead(BTN_LEFT) == LOW) {
    currentScreen = SCREEN_FEED;
    tone(BUZZER_PIN, 1000, 50);
    lastButtonPress = millis();
  } else if (digitalRead(BTN_MIDDLE) == LOW) {
    currentScreen = SCREEN_PLAY;
    tone(BUZZER_PIN, 1500, 50);
    lastButtonPress = millis();
  } else if (digitalRead(BTN_RIGHT) == LOW) {
    currentScreen = SCREEN_SLEEP;
    tone(BUZZER_PIN, 500, 50);
    lastButtonPress = millis();
  }
}

void handleScreenLogic() {
  switch (currentScreen) {
    case SCREEN_FEED:
      pet.hunger += 10;
      if (pet.hunger > 200) pet.hunger = 200;
      logPetStats("Feed updated");
      currentScreen = SCREEN_MAIN;
      break;
    case SCREEN_PLAY:
      pet.love += 10;
      pet.energy -= 5;
      if (pet.love > 100) pet.love = 100;
      if (pet.energy < 0) pet.energy = 0;
      logPetStats("Play updated");
      currentScreen = SCREEN_MAIN;
      break;
    case SCREEN_SLEEP:
      pet.energy += 15;
      if (pet.energy > 200) pet.energy = 200;
      logPetStats("Sleep updated");
      currentScreen = SCREEN_MAIN;
      break;
    case SCREEN_MAIN:
      break;
  }
}

// 'Kona_Happy', 32x32px
const unsigned char PROGMEM Kona_Happy[] = {
  0b00000000, 0b00000000, 0b00000000, 0b00000000,
  0b00000000, 0b00000000, 0b00000000, 0b00000000,
  0b00000000, 0b00000000, 0b00000000, 0b00000000,
  0b00000000, 0b00000000, 0b00000000, 0b00000000,
  0b00000000, 0b11100000, 0b00000000, 0b00000000,
  0b00000111, 0b11110000, 0b00000000, 0b00000000,
  0b00000111, 0b11110000, 0b00000000, 0b00000000,
  0b00011000, 0b00001100, 0b00000000, 0b00000000,
  0b00111010, 0b00101110, 0b00000000, 0b00000000,
  0b00111010, 0b00101110, 0b00000000, 0b10000000,
  0b00111000, 0b00001110, 0b00000000, 0b00101000,
  0b00111000, 0b01001110, 0b00000000, 0b01001000,
  0b00001001, 0b10001000, 0b00000000, 0b00011000,
  0b00000111, 0b11111111, 0b11111111, 0b00110000,
  0b00000000, 0b00100000, 0b00000000, 0b11100100,
  0b00000000, 0b01100000, 0b00000000, 0b10001000,
  0b00000000, 0b01100000, 0b00000000, 0b10000010,
  0b00000000, 0b01100000, 0b00000000, 0b10000000,
  0b00000000, 0b00100000, 0b00000000, 0b10000000,
  0b00000000, 0b00100000, 0b00000000, 0b10000000,
  0b00000000, 0b00011111, 0b11111111, 0b10000000,
  0b00000000, 0b00011011, 0b00001101, 0b10000000,
  0b00000000, 0b00011011, 0b00001101, 0b10000000,
  0b00000000, 0b00010010, 0b00001101, 0b10000000,
  0b00000000, 0b00010010, 0b00001101, 0b00000000,
  0b00000000, 0b00010010, 0b00001001, 0b00000000,
  0b00000000, 0b00010010, 0b00001001, 0b00000000,
  0b00000000, 0b00010010, 0b00001001, 0b00000000,
  0b00000000, 0b00000000, 0b00000000, 0b00000000,
  0b00000000, 0b00000000, 0b00000000, 0b00000000,
  0b00000000, 0b00000000, 0b00000000, 0b00000000,
  0b00000000, 0b00000000, 0b00000000, 0b00000000
};

// 'Kona_Neutral', 32x32px
const unsigned char PROGMEM Kona_Neutral[] = {
  0b00000000, 0b00000000, 0b00000000, 0b00000000,
  0b00000000, 0b00000000, 0b00000000, 0b00000000,
  0b00000000, 0b00000000, 0b00000000, 0b00000000,
  0b00000000, 0b00000000, 0b00000000, 0b00000000,
  0b00000000, 0b11100000, 0b00000000, 0b00000000,
  0b00000111, 0b11110000, 0b00000000, 0b00000000,
  0b00000111, 0b11110000, 0b00000000, 0b00000000,
  0b00011000, 0b00001100, 0b00000000, 0b00000000,
  0b00111010, 0b00101110, 0b00000000, 0b00000000,
  0b00111010, 0b00101110, 0b00000000, 0b00000000,
  0b00111000, 0b00001110, 0b00000000, 0b00000000,
  0b00111001, 0b10001110, 0b00000000, 0b00000000,
  0b00001000, 0b00001000, 0b00000000, 0b00000000,
  0b00000111, 0b11111111, 0b11111111, 0b00000000,
  0b00000000, 0b00100000, 0b00000000, 0b11100000,
  0b00000000, 0b01100000, 0b00000000, 0b10111000,
  0b00000000, 0b01100000, 0b00000000, 0b10001100,
  0b00000000, 0b01100000, 0b00000000, 0b10000000,
  0b00000000, 0b00100000, 0b00000000, 0b10000000,
  0b00000000, 0b00100000, 0b00000000, 0b10000000,
  0b00000000, 0b00011111, 0b11111111, 0b10000000,
  0b00000000, 0b00011011, 0b00001101, 0b10000000,
  0b00000000, 0b00011011, 0b00001101, 0b10000000,
  0b00000000, 0b00010010, 0b00001101, 0b10000000,
  0b00000000, 0b00010010, 0b00001101, 0b00000000,
  0b00000000, 0b00010010, 0b00001001, 0b00000000,
  0b00000000, 0b00010010, 0b00001001, 0b00000000,
  0b00000000, 0b00010010, 0b00001001, 0b00000000,
  0b00000000, 0b00000000, 0b00000000, 0b00000000,
  0b00000000, 0b00000000, 0b00000000, 0b00000000,
  0b00000000, 0b00000000, 0b00000000, 0b00000000,
  0b00000000, 0b00000000, 0b00000000, 0b00000000
};

// 'Kona_Sad', 32x32px
const unsigned char PROGMEM Kona_Sad[] = {
  0b00000000, 0b00000000, 0b00000000, 0b00000000,
  0b00000000, 0b00000000, 0b00000000, 0b00000000,
  0b00000000, 0b00000000, 0b00000000, 0b00000000,
  0b00000000, 0b00000000, 0b00000000, 0b00000000,
  0b00000000, 0b11100000, 0b00000000, 0b00000000,
  0b00000111, 0b11110000, 0b00000000, 0b00000000,
  0b00000111, 0b11110000, 0b00000000, 0b00000000,
  0b00011000, 0b00001100, 0b00000000, 0b00000000,
  0b00111111, 0b01111110, 0b00000000, 0b00000000,
  0b00111010, 0b00101110, 0b00000000, 0b00000000,
  0b00111000, 0b00001110, 0b00000000, 0b00000000,
  0b00111001, 0b10001110, 0b00000000, 0b00000000,
  0b00001000, 0b01001000, 0b00000000, 0b00000000,
  0b00000111, 0b11111111, 0b11111111, 0b00000000,
  0b00000000, 0b00100000, 0b00000000, 0b11100000,
  0b00000000, 0b01100000, 0b00000000, 0b10110000,
  0b00000000, 0b01100000, 0b00000000, 0b10110000,
  0b00000000, 0b01100000, 0b00000000, 0b10010000,
  0b00000000, 0b00100000, 0b00000000, 0b10010000,
  0b00000000, 0b00100000, 0b00000000, 0b10010000,
  0b00000000, 0b00011111, 0b11111111, 0b10000000,
  0b00000000, 0b00011011, 0b00001101, 0b10000000,
  0b00000000, 0b00011011, 0b00001101, 0b10000000,
  0b00000000, 0b00010010, 0b00001101, 0b10000000,
  0b00000000, 0b00010010, 0b00001101, 0b00000000,
  0b00000000, 0b00010010, 0b00001001, 0b00000000,
  0b00000000, 0b00010010, 0b00001001, 0b00000000,
  0b00000000, 0b00010010, 0b00001001, 0b00000000,
  0b00000000, 0b00000000, 0b00000000, 0b00000000,
  0b00000000, 0b00000000, 0b00000000, 0b00000000,
  0b00000000, 0b00000000, 0b00000000, 0b00000000,
  0b00000000, 0b00000000, 0b00000000, 0b00000000
};

// 'Kona_Sleep', 32x32px
const unsigned char PROGMEM Kona_Sleep[] = {
  0b00000000, 0b00000000, 0b00000000, 0b00000000,
  0b00000000, 0b00000000, 0b00000000, 0b00000000,
  0b00000000, 0b00000000, 0b00000000, 0b00000000,
  0b00000000, 0b00000000, 0b00000000, 0b00000000,
  0b00000000, 0b00000000, 0b00000000, 0b00000000,
  0b00000000, 0b00000000, 0b00000000, 0b00000000,
  0b00000001, 0b11111111, 0b11111111, 0b10000000,
  0b00000010, 0b00000000, 0b00000000, 0b01000000,
  0b00000100, 0b00011111, 0b11111100, 0b00100000,
  0b00001000, 0b11100000, 0b00000010, 0b00010000,
  0b00010001, 0b10100000, 0b00000001, 0b00001000,
  0b00010001, 0b00010000, 0b00000000, 0b10001000,
  0b00010001, 0b01111110, 0b00000000, 0b01001000,
  0b00010001, 0b10000001, 0b11000000, 0b01001000,
  0b00010000, 0b10000111, 0b01100000, 0b01001000,
  0b00010000, 0b10010001, 0b00111111, 0b10001000,
  0b00010001, 0b10100101, 0b00000001, 0b10001000,
  0b00010010, 0b01111110, 0b01110011, 0b00001000,
  0b00010010, 0b01000000, 0b00011110, 0b00001000,
  0b00010010, 0b11000000, 0b00000000, 0b00001000,
  0b00011011, 0b10000000, 0b00000000, 0b00011000,
  0b00011101, 0b00000000, 0b00000000, 0b00111000,
  0b00001110, 0b00000000, 0b00000000, 0b01110000,
  0b00000111, 0b11111111, 0b11111111, 0b11100000,
  0b00000011, 0b11111111, 0b11111111, 0b11000000,
  0b00000001, 0b11111111, 0b11111111, 0b10000000,
  0b00000000, 0b00000000, 0b00000000, 0b00000000,
  0b00000000, 0b00000000, 0b00000000, 0b00000000,
  0b00000000, 0b00000000, 0b00000000, 0b00000000,
  0b00000000, 0b00000000, 0b00000000, 0b00000000,
  0b00000000, 0b00000000, 0b00000000, 0b00000000,
  0b00000000, 0b00000000, 0b00000000, 0b00000000
};

// Array of all bitmaps Kona. (Total bytes used to store images in PROGMEM = 576)
const int allArray_LEN = 4;
const unsigned char* allArray[4] = {
  Kona_Happy,
  Kona_Neutral,
  Kona_Sad,
  Kona_Sleep
};

void drawBar(int x, int y, int value, int maxValue) {
  int barWidth = 100;
  int barHeight = 6;
  int safeMax = max(1, maxValue);
  int safeValue = constrain(value, 0, safeMax);
  int filledWidth = map(safeValue, 0, safeMax, 0, barWidth);

  display.fillRect(x, y, filledWidth, barHeight, SSD1306_WHITE);
  display.drawRect(x, y, barWidth, barHeight, SSD1306_WHITE);
}

void render() {
  display.clearDisplay();

  const unsigned char* sprite;
  if (pet.hunger < 30 || pet.energy < 30 || pet.love < 30 || pet.life < 20) {
    sprite = Kona_Sad;
  } else if (pet.hunger > 70 && pet.energy > 70 && pet.love > 70 && pet.life > 60) {
    sprite = Kona_Happy;
  } else {
    sprite = Kona_Neutral;
  }

  display.drawBitmap((SCREEN_WIDTH - 32) / 1.3, 10, sprite, 32, 32, SSD1306_WHITE);
  display.setTextSize(1);

  display.setCursor(0, 14);
  display.print("LIF");
  display.setCursor(30, 14);
  display.print(pet.life);

  display.setCursor(0, 24);
  display.print("LOV");
  display.setCursor(30, 24);
  display.print(pet.love);

  display.setCursor(0, 34);
  display.print("HUN");
  display.setCursor(30, 34);
  display.print(pet.hunger);

  display.setCursor(0, 44);
  display.print("ENE");
  display.setCursor(30, 44);
  display.print(pet.energy);

  display.setCursor(0, 56);
  display.println("[Feed] [Play] [Sleep]");

  display.display();
}

void loop() {
  checkButtons();
  updatePet();
  handleScreenLogic();
  render();
  delay(100);
}

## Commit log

2026-05-16 Update README with BOM and cost details
    Added detailed cost breakdown for components and fees.
2026-05-16 Setup Files
    Added some organization folders, added KiCad production files, added PCB 3D models, added PCB Gerber files.
    [1_01 Table of Contents.kicad_sch, 2_02 Block Diagram.kicad_sch, 3_03 Power IN & MCU GPIOs.kicad_sch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]
2026-05-16 Removed unnecessary folder
    And updated file names
    [1_01 Table of Contents.kicad_sch, 2_02 Block Diagram.kicad_sch, 3_03 Power IN & MCU GPIOs.kicad_sch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]
2026-05-17 Added Componet Step Files
    [4 Pin Header STEP.step, 7 Pin header STEP.step, seeed-studio-xiao-esp32c6-v2.step]
2026-05-19 Updated .step files for headers
    [4 Pin Header STEP.step, 4 Pin Header.step, 7 Pin header STEP.step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]
2026-05-22 Update screw specifications in README
2026-05-23 Exported CAD Files and 3D Print Files
    Plus added a simple repo cover image
    [PetPad Case Bottom.3mf, PetPad Case Top.3mf, PetPad Repo Cover.blend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]
2026-05-23 Firmware files added
    Also reorganized some folders
    [1_01 Table of Contents.kicad_sch, 2_02 Block Diagram.kicad_sch, 3_03 Power IN & MCU GPIOs.kicad_sch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]
2026-05-26 Firmware Arduino setup and first Sprite pic
    Setup the visual studio code addon for Arduino projects, made buttons do stuff and buzzer ring, also made first pet sprite.
    [partitions.csv]
2026-05-27 Enhance README with features and project details
    Added detailed features, PCB information, case overview, BOM, and software used sections to README.
2026-05-30 Added debug logs and new build
    [partitions.csv]
2026-05-30 Update Stat screen and fix wokwi sim
    [PetPad_Firm.ino]
2026-06-01 Promo Gif and github cover pic v2
    [PetPad Main.blend, PetPad Repo Cover.blend]
2026-06-01 Updated CAD files and zine progress
    [PetPad Main.blend, PetPad Zine.blend, Videocraft PetPad.f3z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]
2026-06-02 Added lights to zine, background, and a qr code
    [PetPad Zine.blend]
2026-06-04 THE FINAL ZINE
    [PetPad Zine.blend]
2026-06-04 Create PetPad BOM.csv
    [PetPad BOM.csv]
2026-06-05 Update total fees and add BOM section in README
2026-06-05 Update battery price and fees in BOM
2026-06-05 Update soldering iron price and total cost
2026-06-10 KiCad Removed due to switching to easyeda
    [1_01 Table of Contents.kicad_sch, 2_02 Block Diagram.kicad_sch, 3_03 Power IN & MCU GPIOs.kicad_sch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]
2026-06-10 Revert "KiCad Removed due to switching to easyeda"
    This reverts commit 66cc2478bb831fb9d475607df87d2e1e71403cc5.
    [1_01 Table of Contents.kicad_sch, 2_02 Block Diagram.kicad_sch, 3_03 Power IN & MCU GPIOs.kicad_sch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]
2026-06-12 Update BOM
    [PetPad BOM.csv, PetPad_BOM.csv]
2026-08-13 Bottom Case battery size update
    [PetPad Case Bottom.3mf, Videocraft PetPad.f3z, Videocraft PetPad.obj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]
2026-08-14 slight update on screw head stoppers
    make thicker from -.7 mm to -1mm
    [PetPad Case Bottom.3mf, Videocraft PetPad.f3z, Videocraft PetPad.obj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]
2026-08-15 Battey holder update + larger button holes for fingers
    [PetPad Case Bottom.3mf, PetPad Case Top.3mf, Videocraft PetPad.f3z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]
